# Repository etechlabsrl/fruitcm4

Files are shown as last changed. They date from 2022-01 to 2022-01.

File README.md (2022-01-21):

# Salmonberry Pi, Fruit \ 'früt \

<a href="https://www.raspberrypi.org">Raspberry Pi Logo</a>

> The Raspberry Pi is a series of credit card-sized single-board computers developed in the United Kingdom by the Raspberry Pi Foundation to promote the teaching of basic computer science in schools and developing countries. Official Link: [Raspberry Pi Foundation Homepage](https://raspberrypi.org), [Raspberry Pi Computer Homepage](https://www.raspberrypi.com)

<p>

Salmonberry Pi is a group of open source hardware projects which allow the construction of cluster hardware from small to arbitrary size using Raspberry Pi platforms.  This includes the Raspberry Pi Compute Module 4 (CM4) Raspberry Pi Zero 2 W, Raspberry Pi 4 Model B, and Raspberry Pi RP2040 microcontrollers.

The goals of this project are to provide:
- infrastructure for clustering nodes
- self-sufficient nodes by default (no 'leader')
- remotely monitoring
- remote management
- standard form factors and connectors, although perhaps repurposed

The component projects are:
- [Face CM4](https://github.com/salmonberrypi/facecm4), 8TE 3U faceplate with jacks, microSD card slot and LEDs.
- [Fruit CM4](https://github.com/salmonberrypi/fruitcm4), carrier board for CM4, general purpose compute or storage or both.
- [Graft](https://github.com/salmonberrypi/graft), development board to bring up Fruit board, allows diversion to on-board connectors for rhizome served power and signals. Can be used with or without rhizome boards. (out of date)
- [Thorn](https://github.com/salmonberrypi/thorn), passive board to protect the male plug on the Fruit or Graft boards. (out of date)
- [Rhizome](https://github.com/salmonberrypi/rhizome), life support systems and connectivity
- [Stem 3U x 160mm](https://github.com/salmonberrypi/stem_3U_160mm_X4), 3U x 160mm passive slot extension for debugging

(images are from a previous revision and out of date, shown for reference)

PCB front:

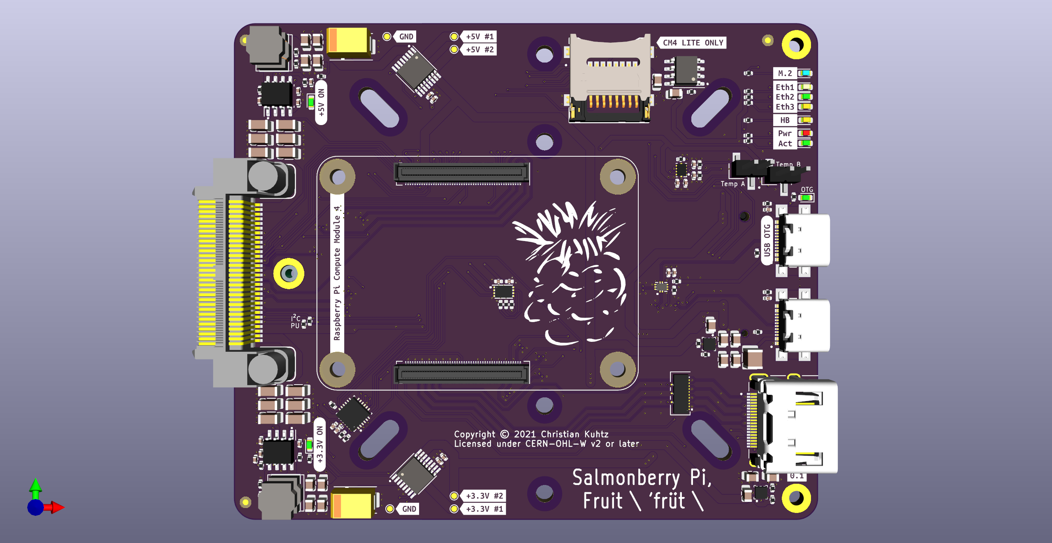
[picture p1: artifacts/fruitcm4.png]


PCB back:

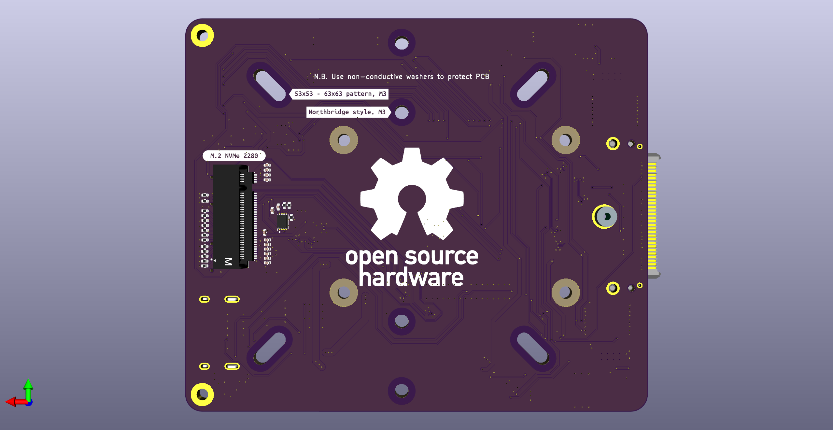
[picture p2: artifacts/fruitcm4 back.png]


Dimensions: 160 x 100mm (0.562 x 0.478 [bananas](http://bananaforscale.info/#!/convert/length/bananas/millimeters)) without connector and faceplate, 4 layer PCB (pwr/signal, gnd, gnd, pwr/signal).

Review [Interactive BOM](https://htmlpreview.github.io/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).

Review [Schematic](https://github.com/salmonberrypi/fruitcm4/blob/main/artifacts/fruitcm4%20schematic.pdf).

---

Designed in [KiCad 6](https://kicad.org) on [Ubuntu](https://ubuntu.org) 21.10 (impish).

---

Raspberry Pi is a trademark of Raspberry Pi Trading

---

Copyright (C) 2022 Christian Kuhtz

This source describes Open Hardware and is licensed under the CERN-OHLW v2
<P>
You may redistribute and modify this documentation and make products
using it under the terms of the CERN-OHL-W v2 (https:/cern.ch/cern-ohl).
<P>
This documentation is distributed WITHOUT ANY EXPRESS OR IMPLIED
WARRANTY, INCLUDING OF MERCHANTABILITY, SATISFACTORY QUALITY
AND FITNESS FOR A PARTICULAR PURPOSE. Please see the <a href="https://ohwr.org/cern_ohl_w_v2.txt">CERN-OHL-W v2</a> for applicable conditions.
<P>
Source location: https://github.com/salmonberrypi
<P>
As per CERN-OHL-W v2 section 4.1, should You produce hardware based on
these sources, You must maintain the Source Location visible on the
external case of the Salmonberry Pi or other product you make using
this documentation.

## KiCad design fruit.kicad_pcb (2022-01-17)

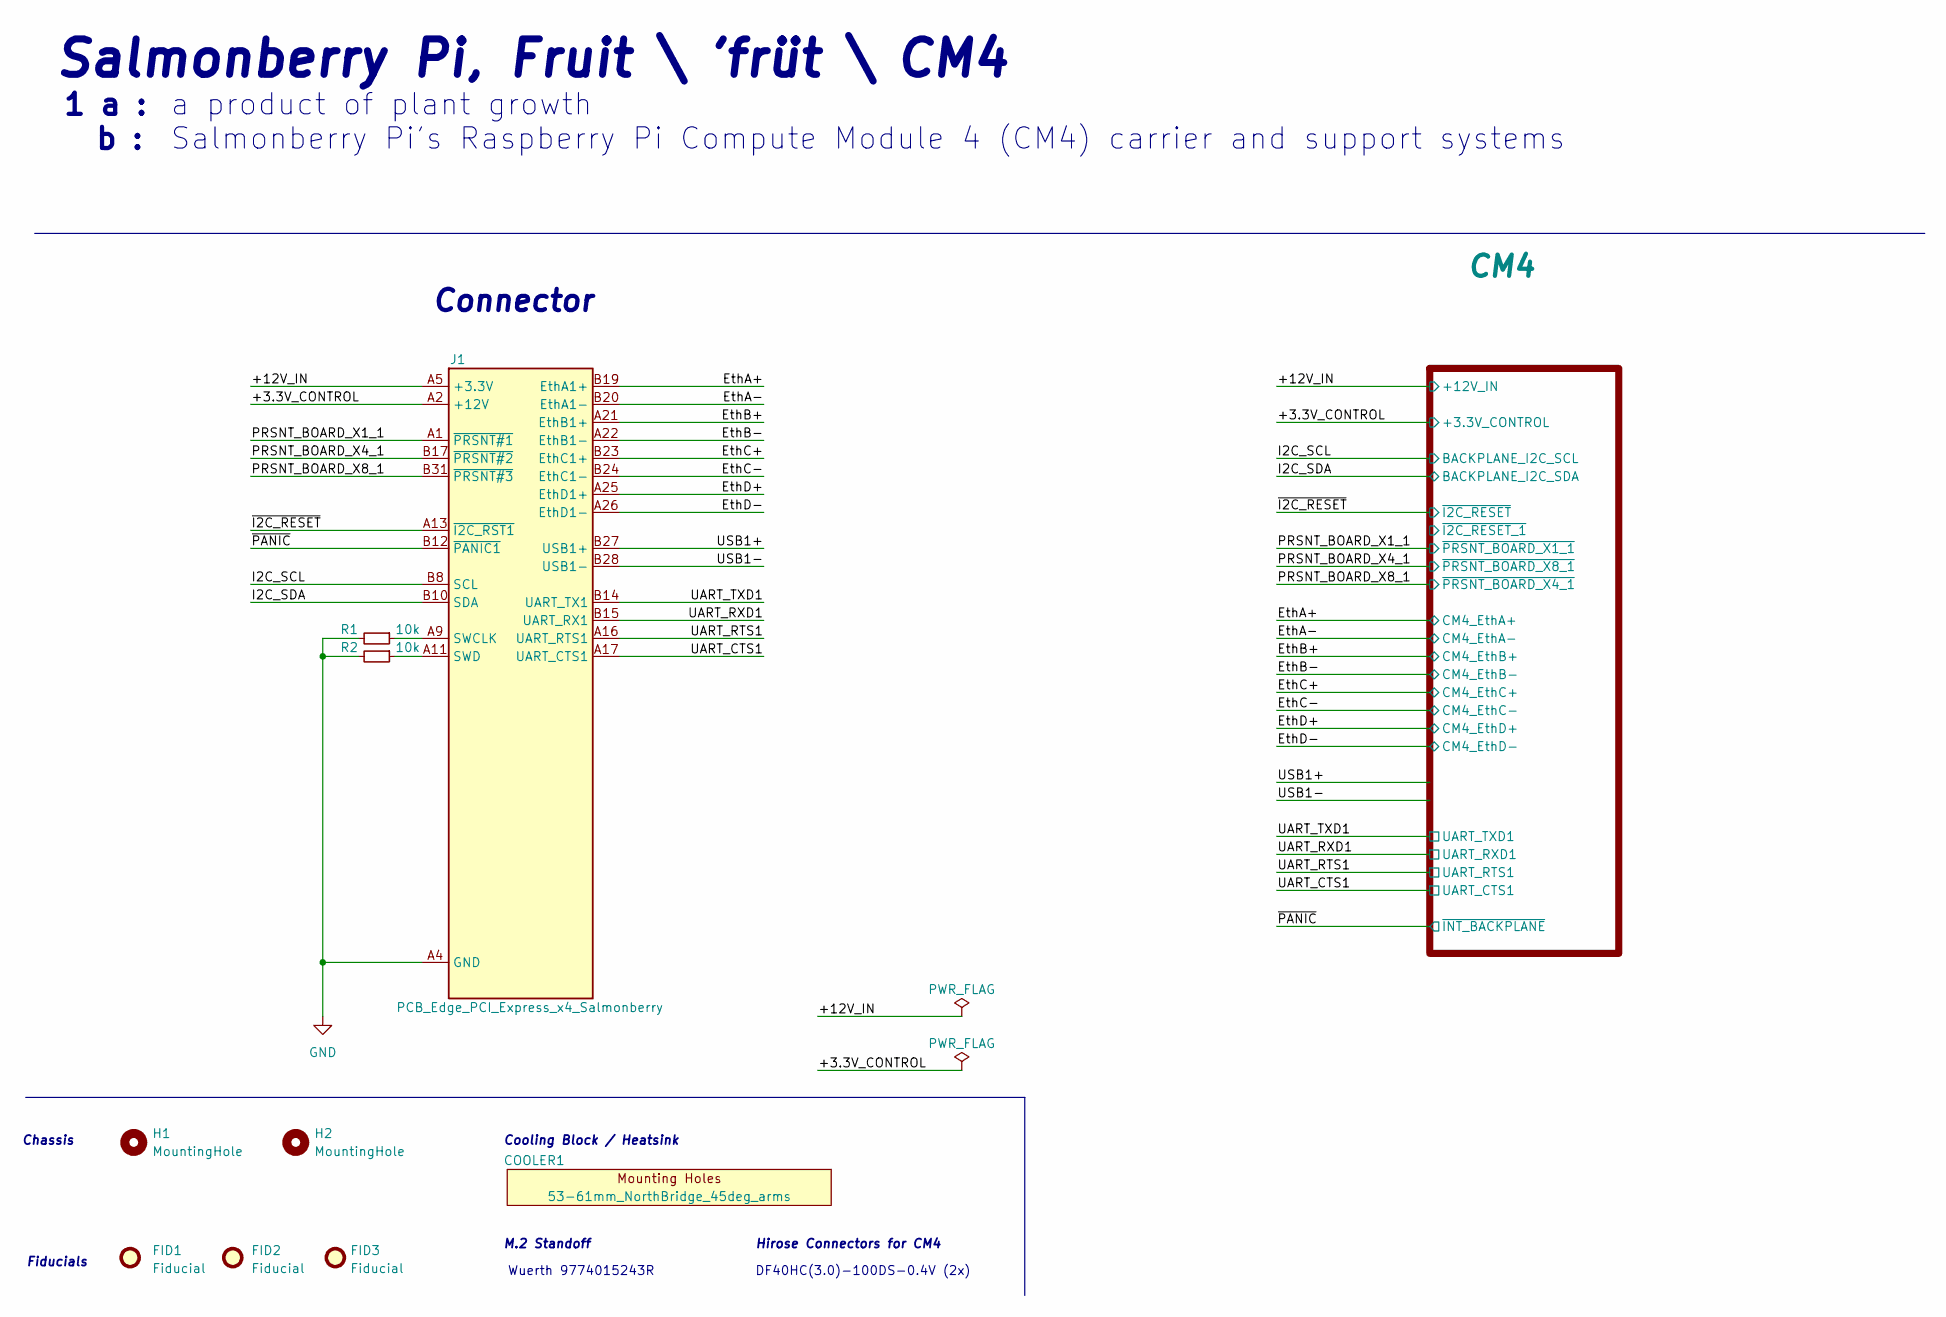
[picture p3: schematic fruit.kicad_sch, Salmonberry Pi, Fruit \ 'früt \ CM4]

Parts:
COOLER1: 53-61mm_NorthBridge_45deg_arms
FID1, FID2, FID3: Fiducial; Fiducial_1mm_Mask2mm
H1, H2: MountingHole; MountingHole_2.7mm_M2.5
J1: PCB_Edge_PCI_Express_x4_Salmonberry; BUS_PCIexpress_x4_Salmonberry_reduced_shoulders
R1, R2: 10k; R_0402_1005Metric

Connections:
+3.3V: J1.A5 (+3.3V), J1.A6 (+3.3V), J1.B5 (+3.3V), J1.B6 (+3.3V); also elsewhere on the board
+12V: J1.A2 (+12V), J1.A3 (+12V), J1.B1 (+12V), J1.B2 (+12V), J1.B3 (+12V); also elsewhere on the board
/EthA+: J1.B19 (EthA1+); also elsewhere on the board
/EthA-: J1.B20 (EthA1-); also elsewhere on the board
/EthB+: J1.A21 (EthB1+); also elsewhere on the board
/EthB-: J1.A22 (EthB1-); also elsewhere on the board
/EthC+: J1.B23 (EthC1+); also elsewhere on the board
/EthC-: J1.B24 (EthC1-); also elsewhere on the board
/EthD+: J1.A25 (EthD1+); also elsewhere on the board
/EthD-: J1.A26 (EthD1-); also elsewhere on the board
/I2C_SCL: J1.B8 (SCL); also elsewhere on the board
/I2C_SDA: J1.B10 (SDA); also elsewhere on the board
/PRSNT_BOARD_X1_1: J1.A1 (~PRSNT#1); also elsewhere on the board
/PRSNT_BOARD_X4_1: J1.B17 (~PRSNT#2); also elsewhere on the board
/PRSNT_BOARD_X8_1: J1.B31 (~PRSNT#3); also elsewhere on the board
/UART_CTS1: J1.A17 (UART_CTS1); also elsewhere on the board
/UART_RTS1: J1.A16 (UART_RTS1); also elsewhere on the board
/UART_RXD1: J1.B15 (UART_RX1); also elsewhere on the board
/UART_TXD1: J1.B14 (UART_TX1); also elsewhere on the board
/USB1+: J1.B27 (USB1+)
/USB1-: J1.B28 (USB1-)
/~I2C_RESET: J1.A13 (~I2C_RST1); also elsewhere on the board
/~PANIC: J1.B12 (~PANIC1); also elsewhere on the board
GND: J1.A4 (GND), J1.A7 (GND), J1.A8 (GND), J1.A10 (GND), J1.A12 (GND), J1.A14 (GND), J1.A15 (GND), J1.A18 (GND), J1.A19 (GND), J1.A20 (GND), J1.A23 (GND), J1.A24 (GND), J1.A27 (GND), J1.A28 (GND), J1.A29 (GND), J1.A30 (GND), J1.A31 (GND), J1.A32 (GND), J1.B4 (GND), J1.B7 (GND), J1.B9 (GND), J1.B11 (GND), J1.B13 (GND), J1.B16 (GND), J1.B18 (GND), J1.B21 (GND), J1.B22 (GND), J1.B25 (GND), J1.B26 (GND), J1.B29 (GND), J1.B30 (GND), J1.B32 (GND), R1.2, R2.2; also elsewhere on the board
unnamed: J1.A9 (SWCLK), R1.1
unnamed: J1.A11 (SWD), R2.1

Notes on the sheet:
Cooling Block / Heatsink
M.2 Standoff
Salmonberry Pi, Fruit \ 'früt \ CM4
Fiducials
1 a : b :
a product of plant growth Salmonberry Pi's Raspberry Pi Compute Module 4 (CM4) carrier and support systems
Hirose Connectors for CM4
DF40HC(3.0)-100DS-0.4V (2x)
Chassis
Wuerth 9774015243R
Connector

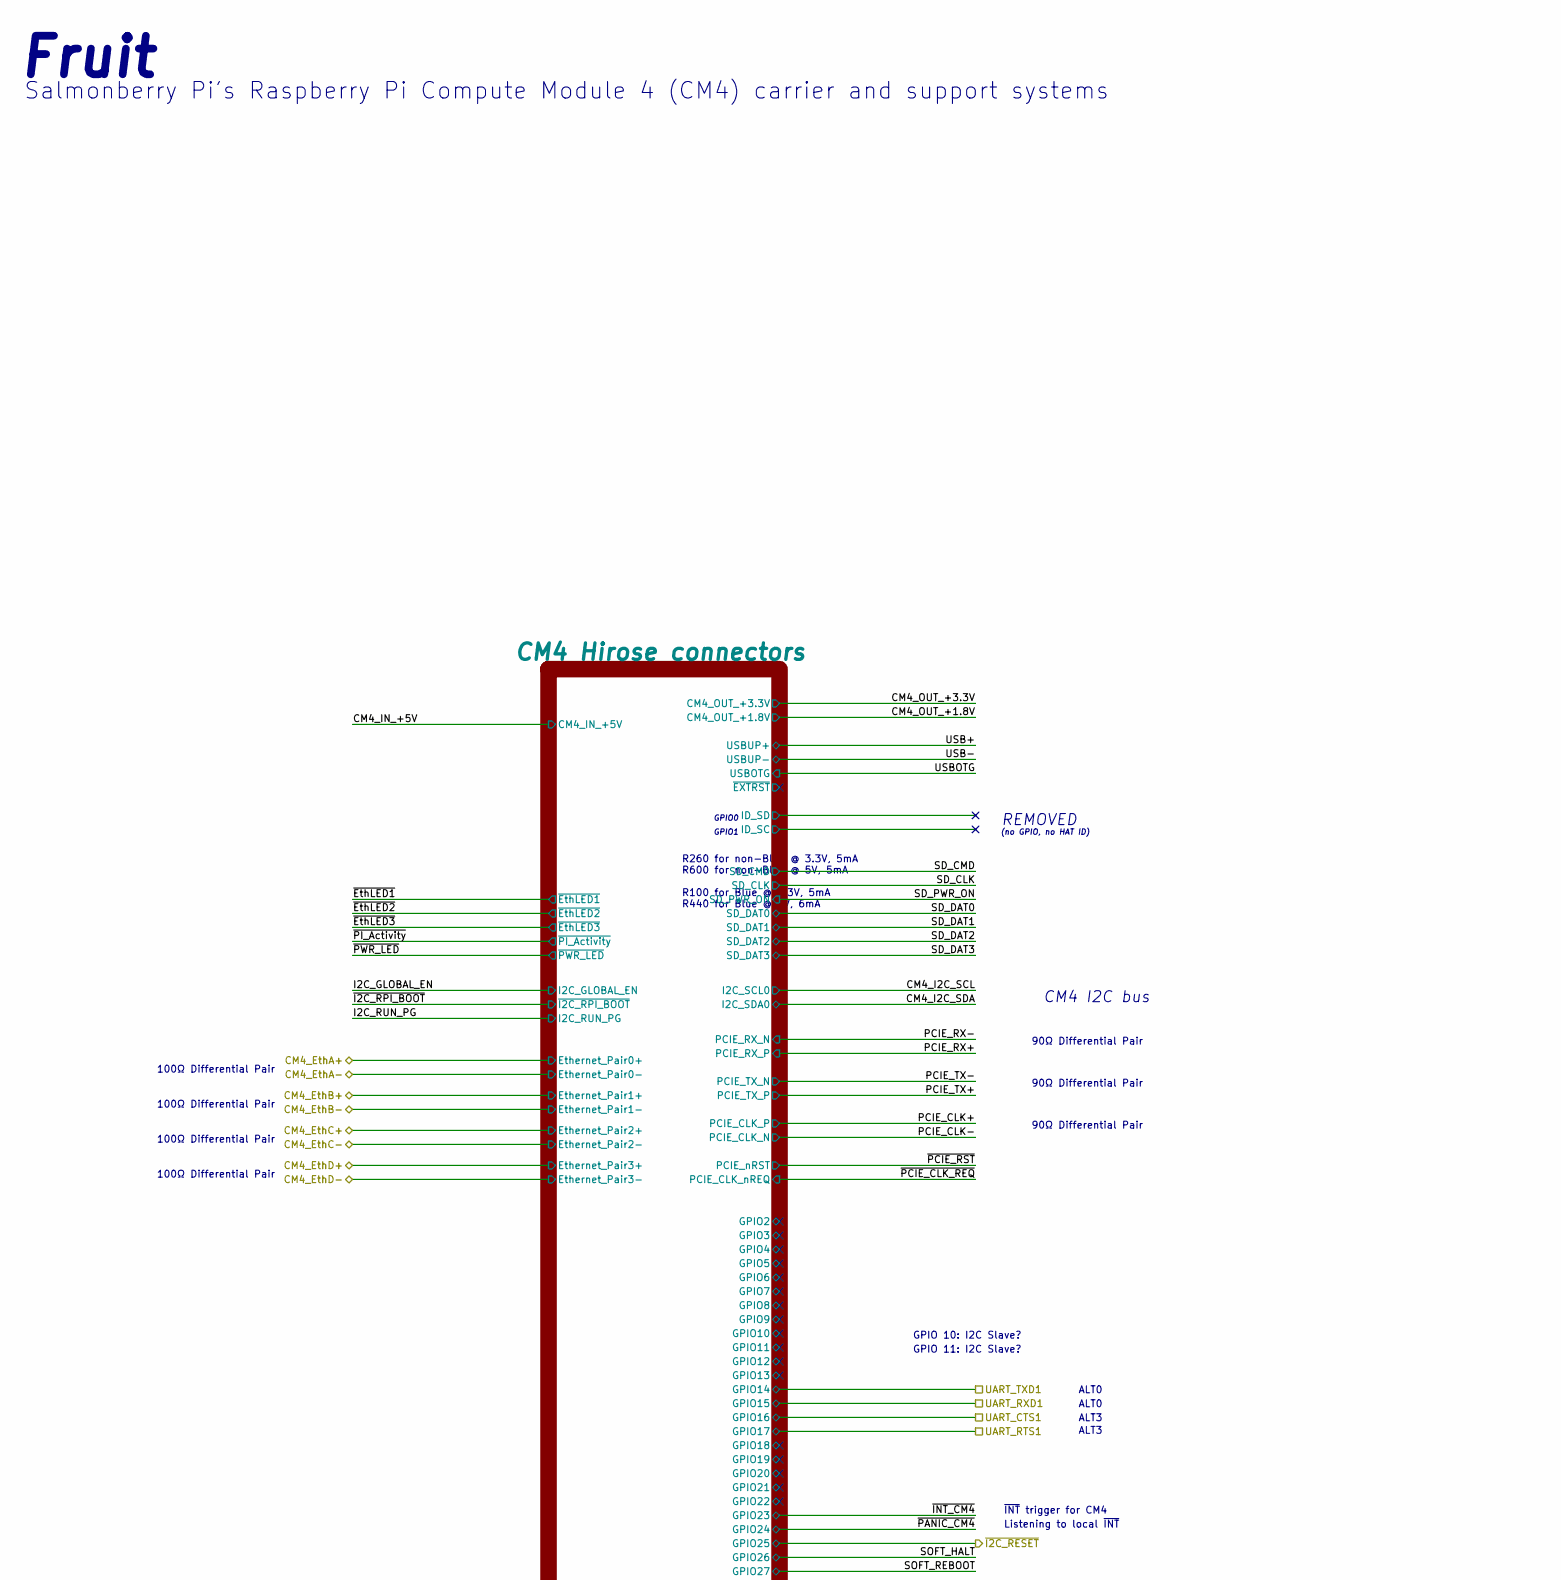
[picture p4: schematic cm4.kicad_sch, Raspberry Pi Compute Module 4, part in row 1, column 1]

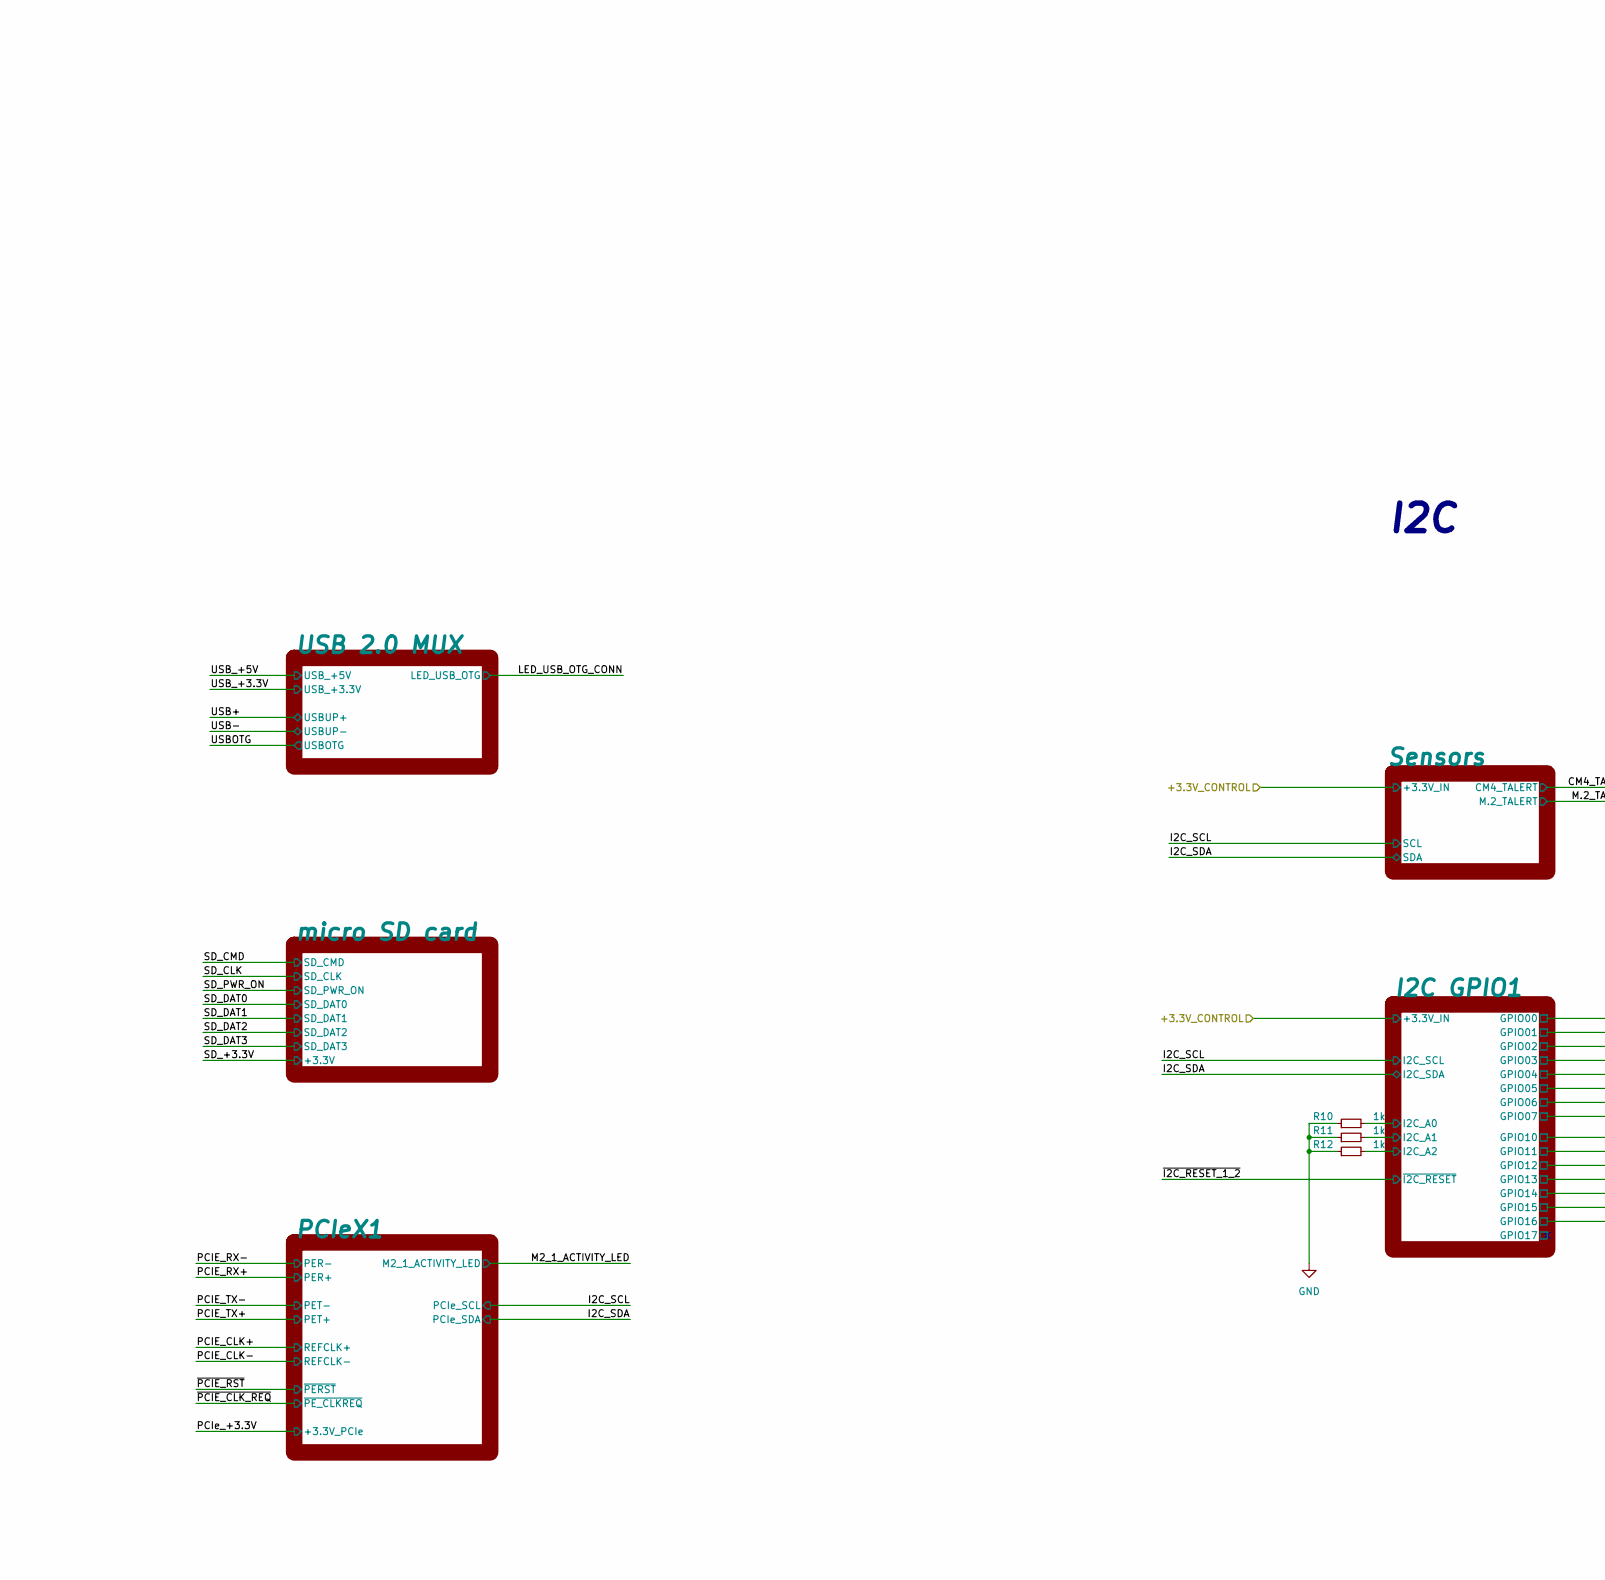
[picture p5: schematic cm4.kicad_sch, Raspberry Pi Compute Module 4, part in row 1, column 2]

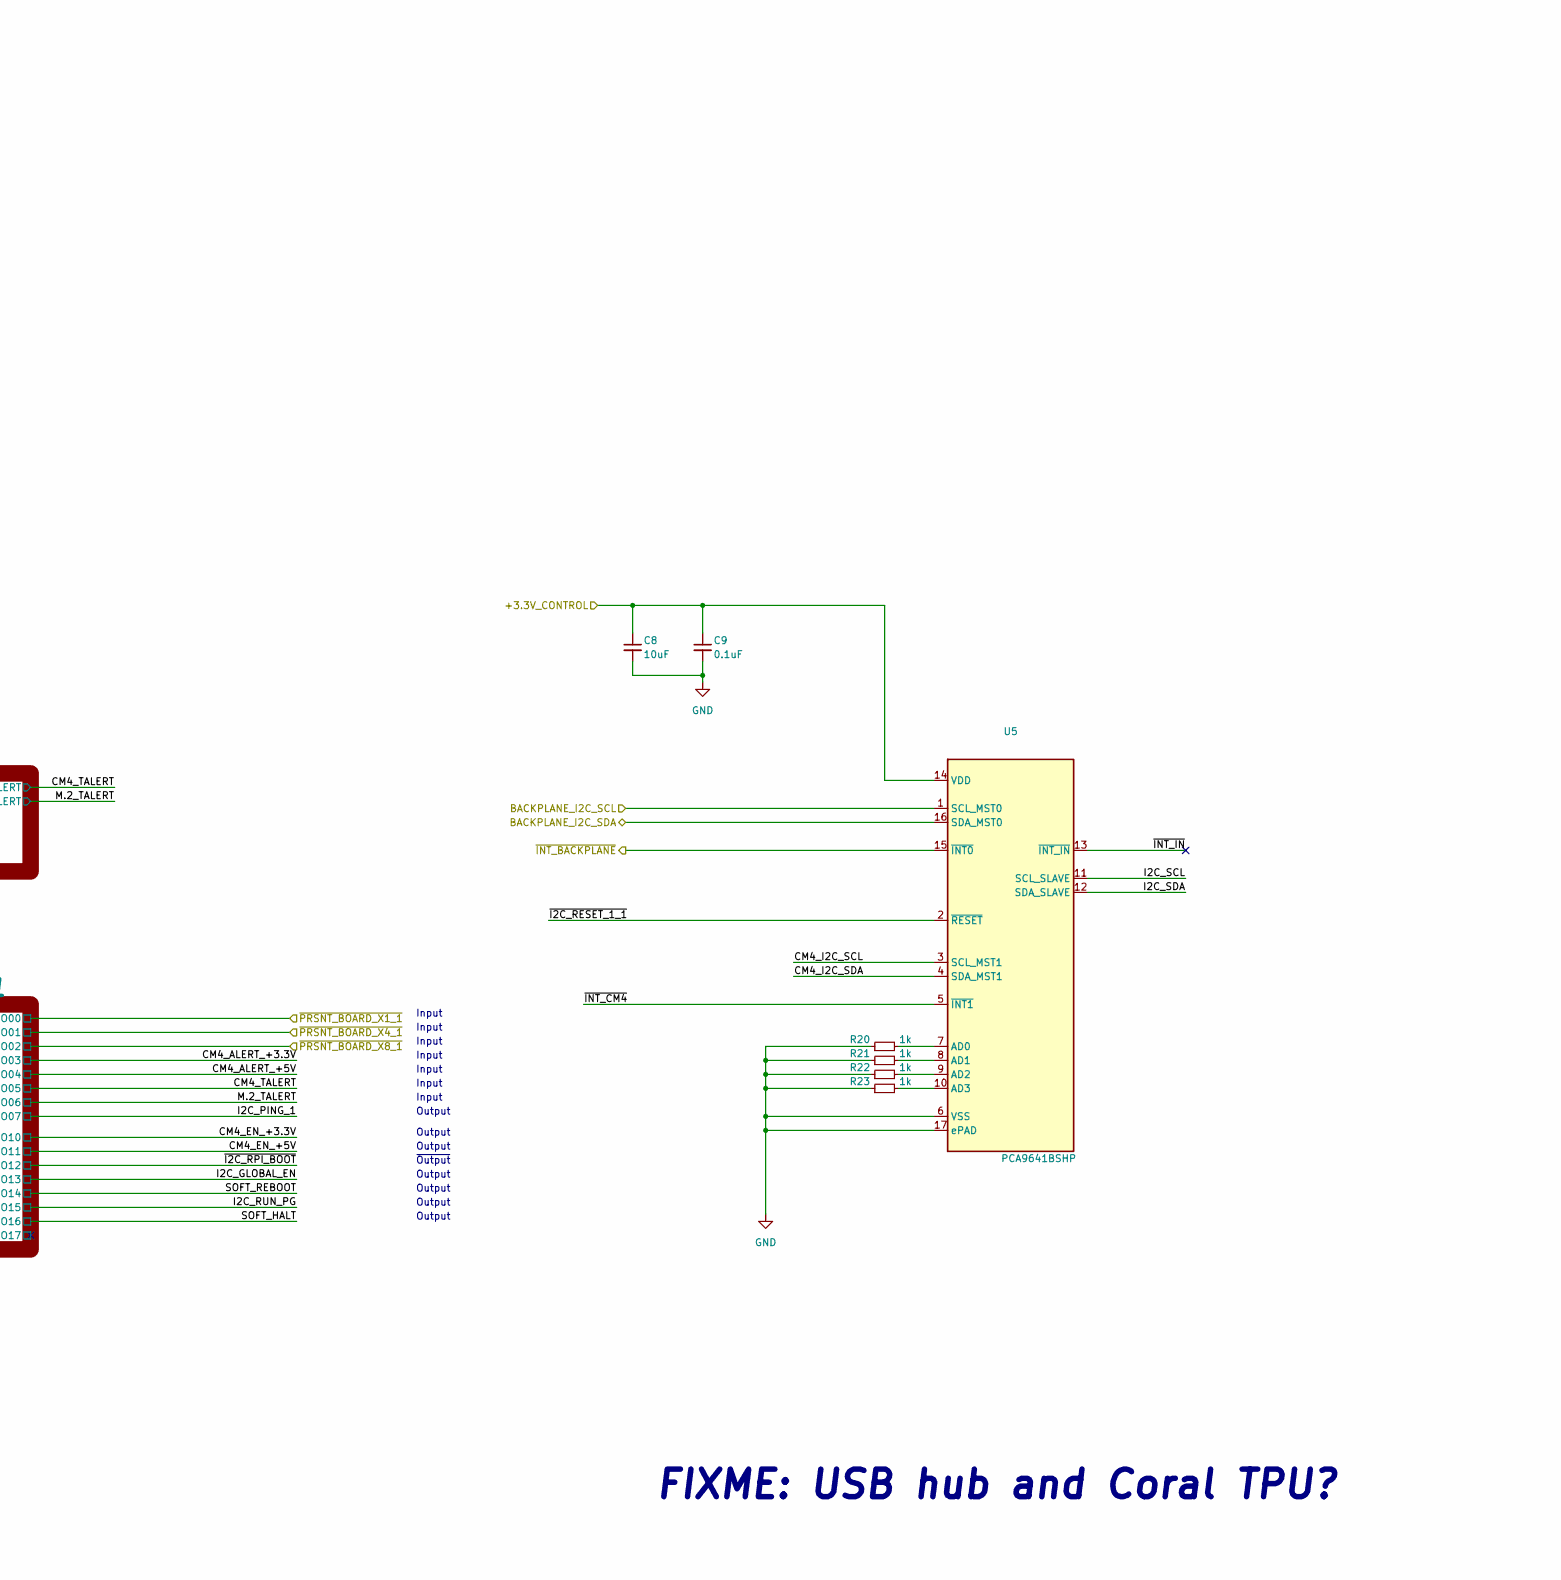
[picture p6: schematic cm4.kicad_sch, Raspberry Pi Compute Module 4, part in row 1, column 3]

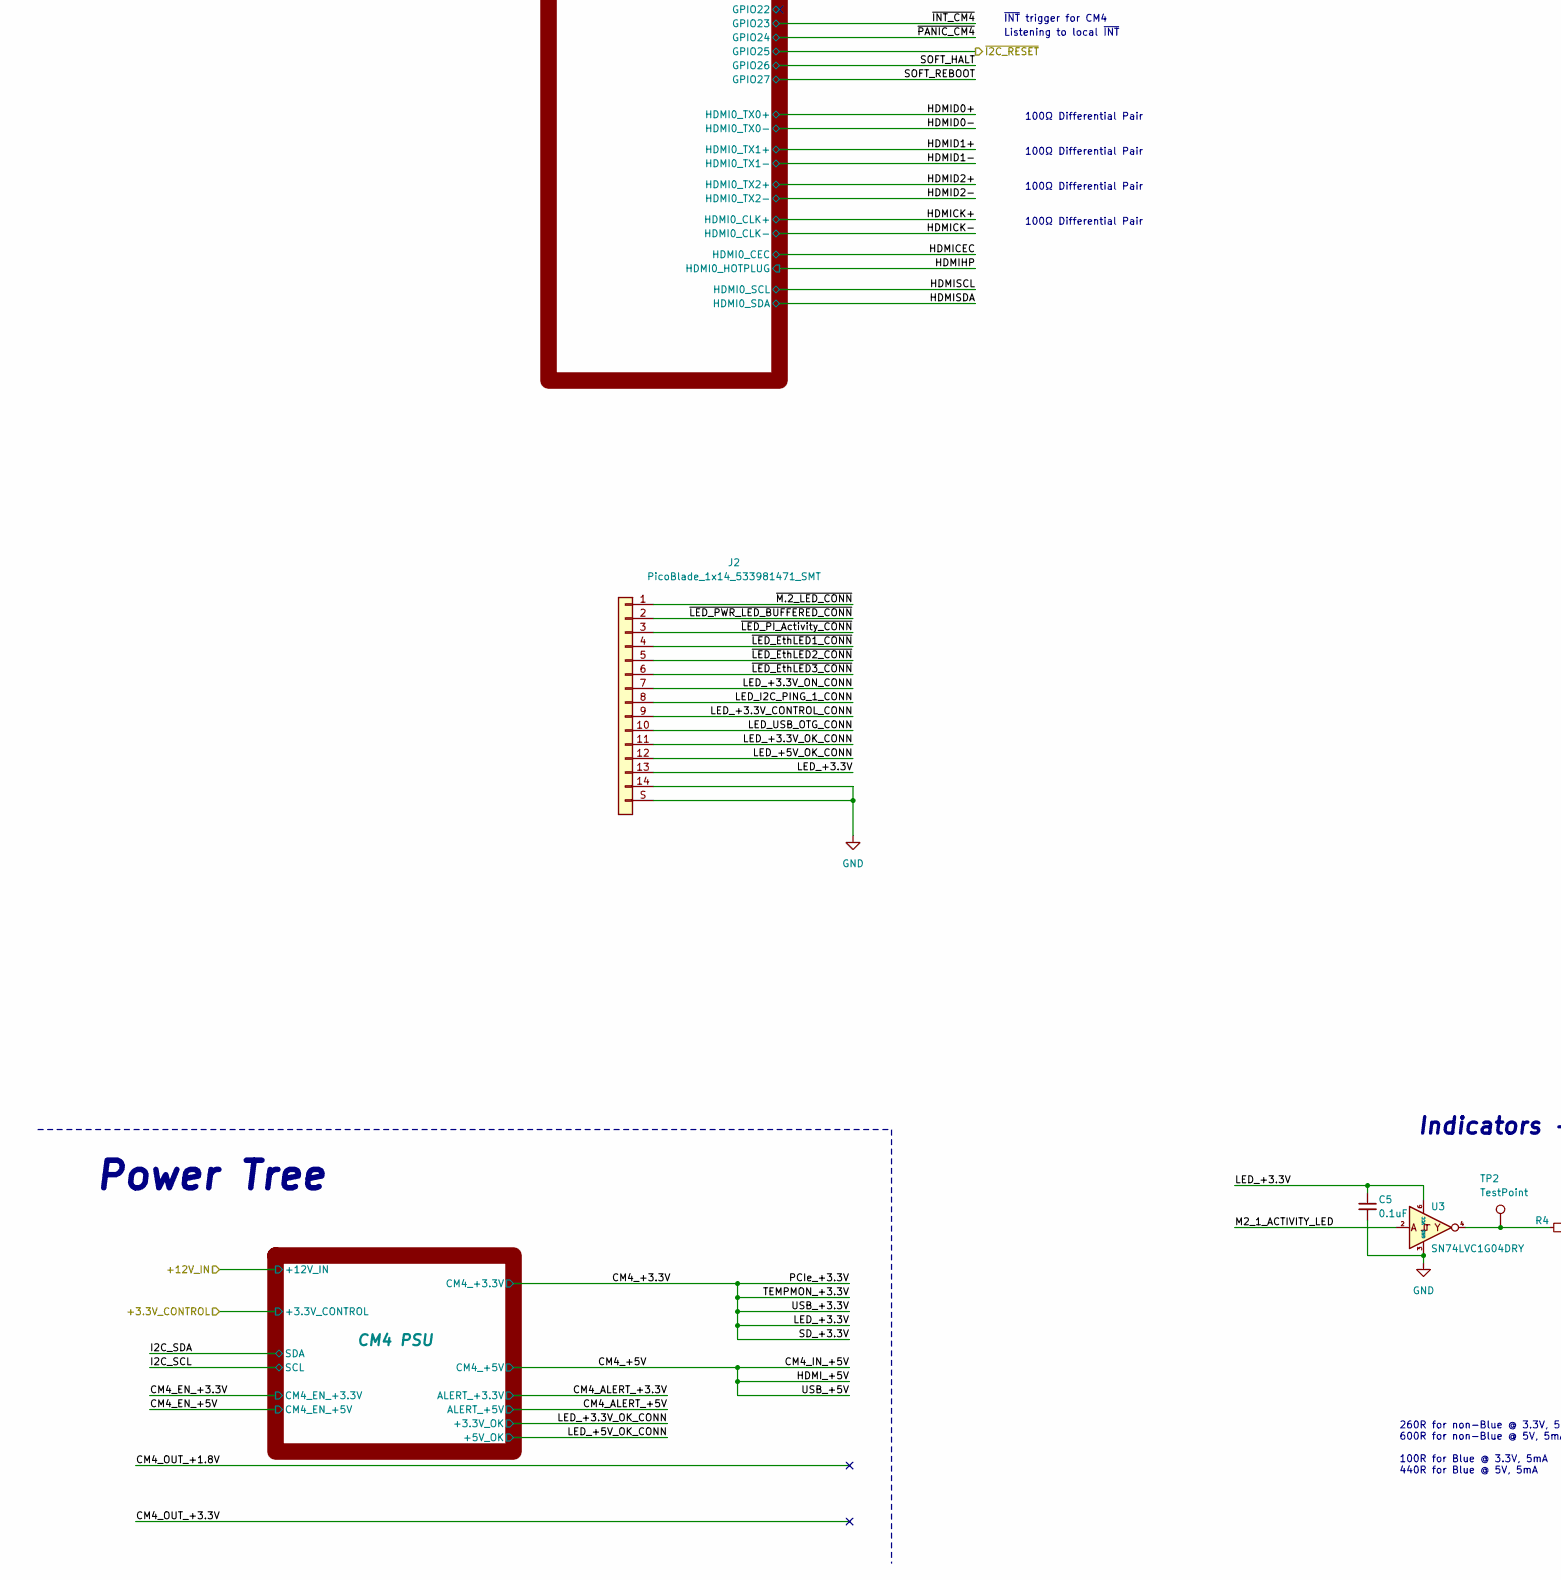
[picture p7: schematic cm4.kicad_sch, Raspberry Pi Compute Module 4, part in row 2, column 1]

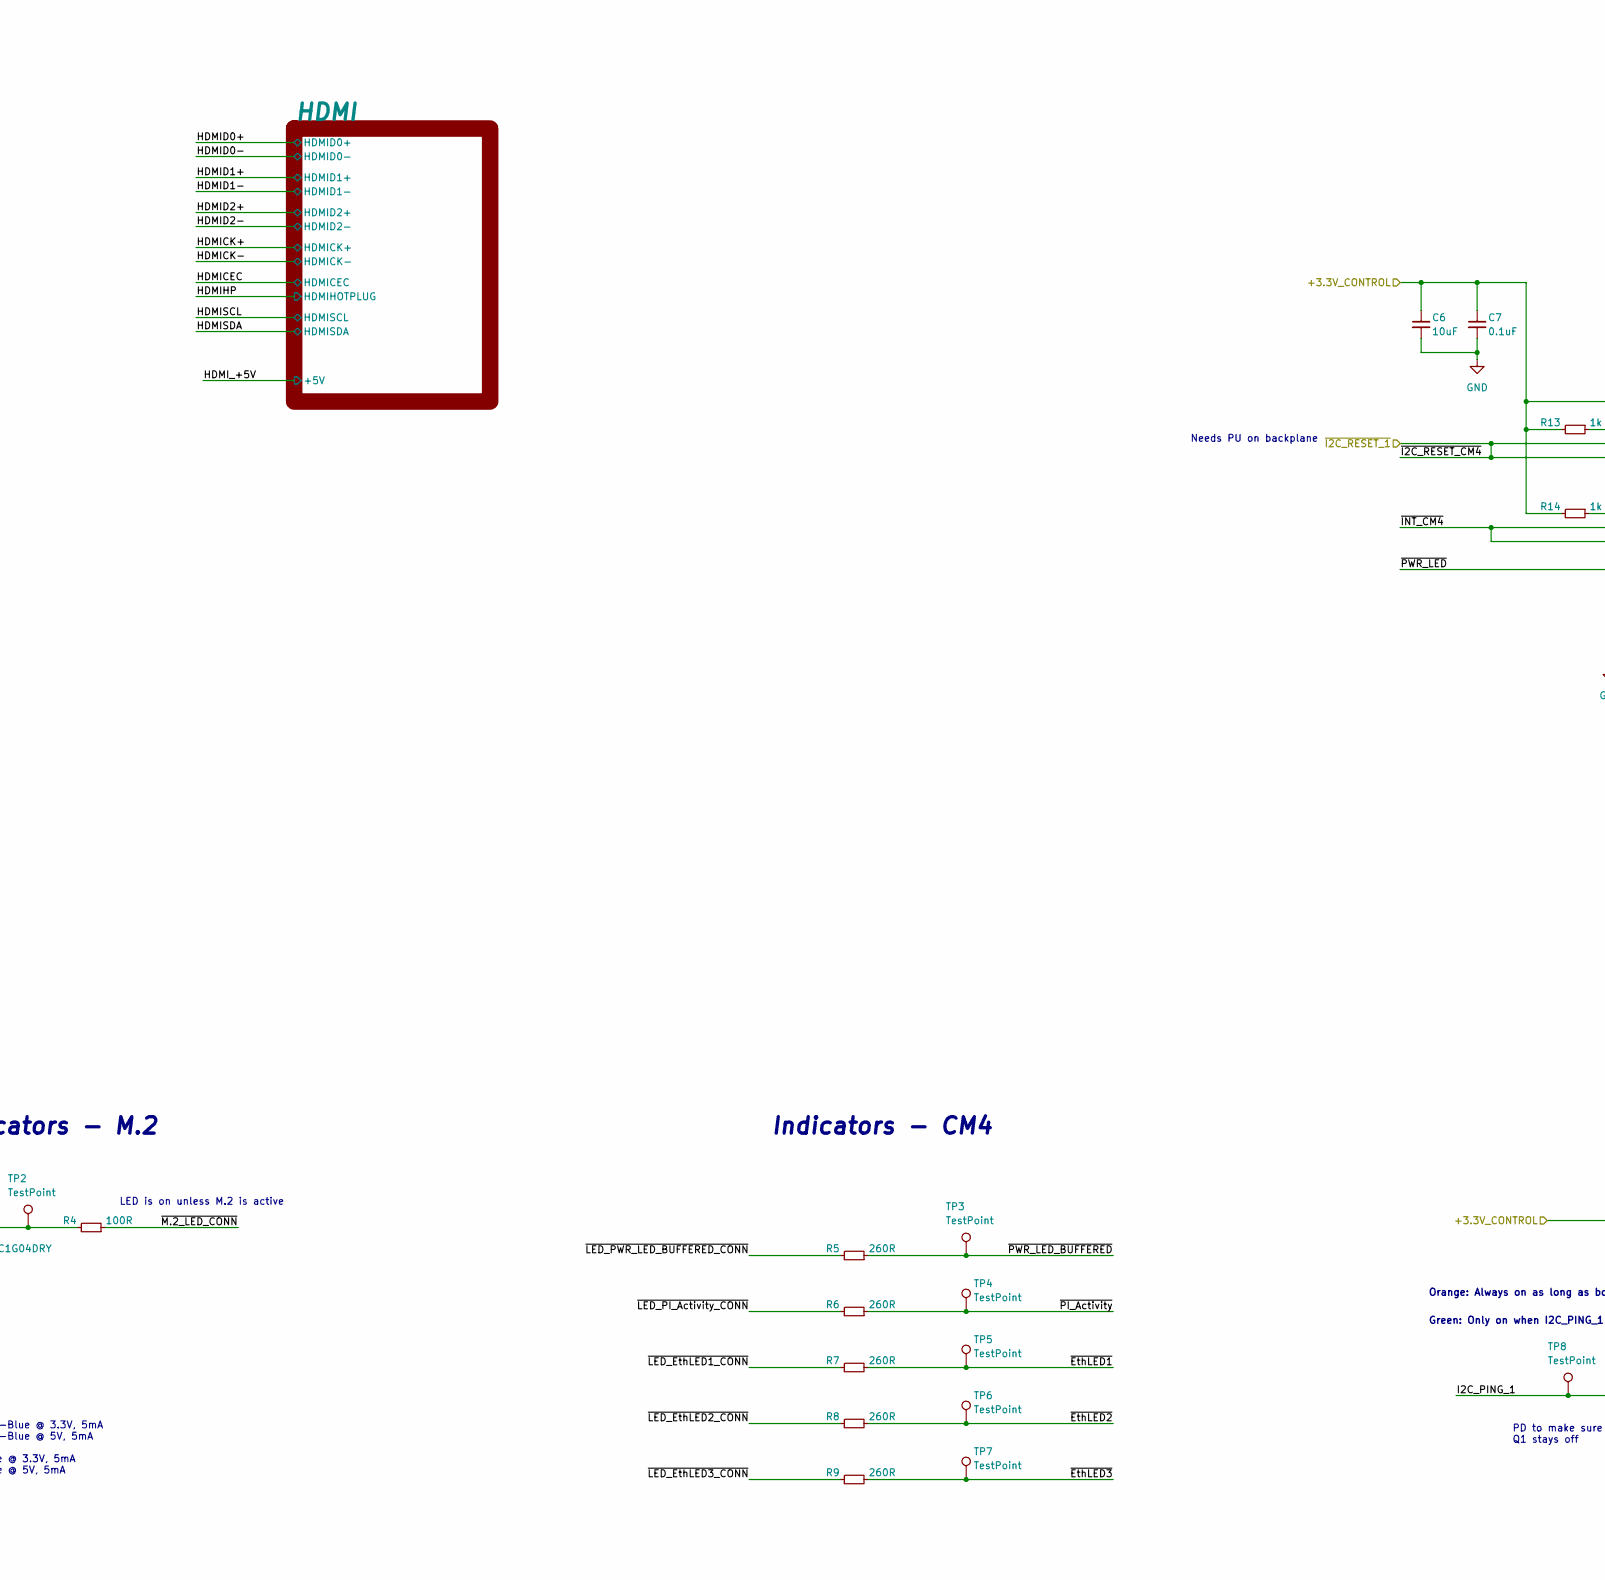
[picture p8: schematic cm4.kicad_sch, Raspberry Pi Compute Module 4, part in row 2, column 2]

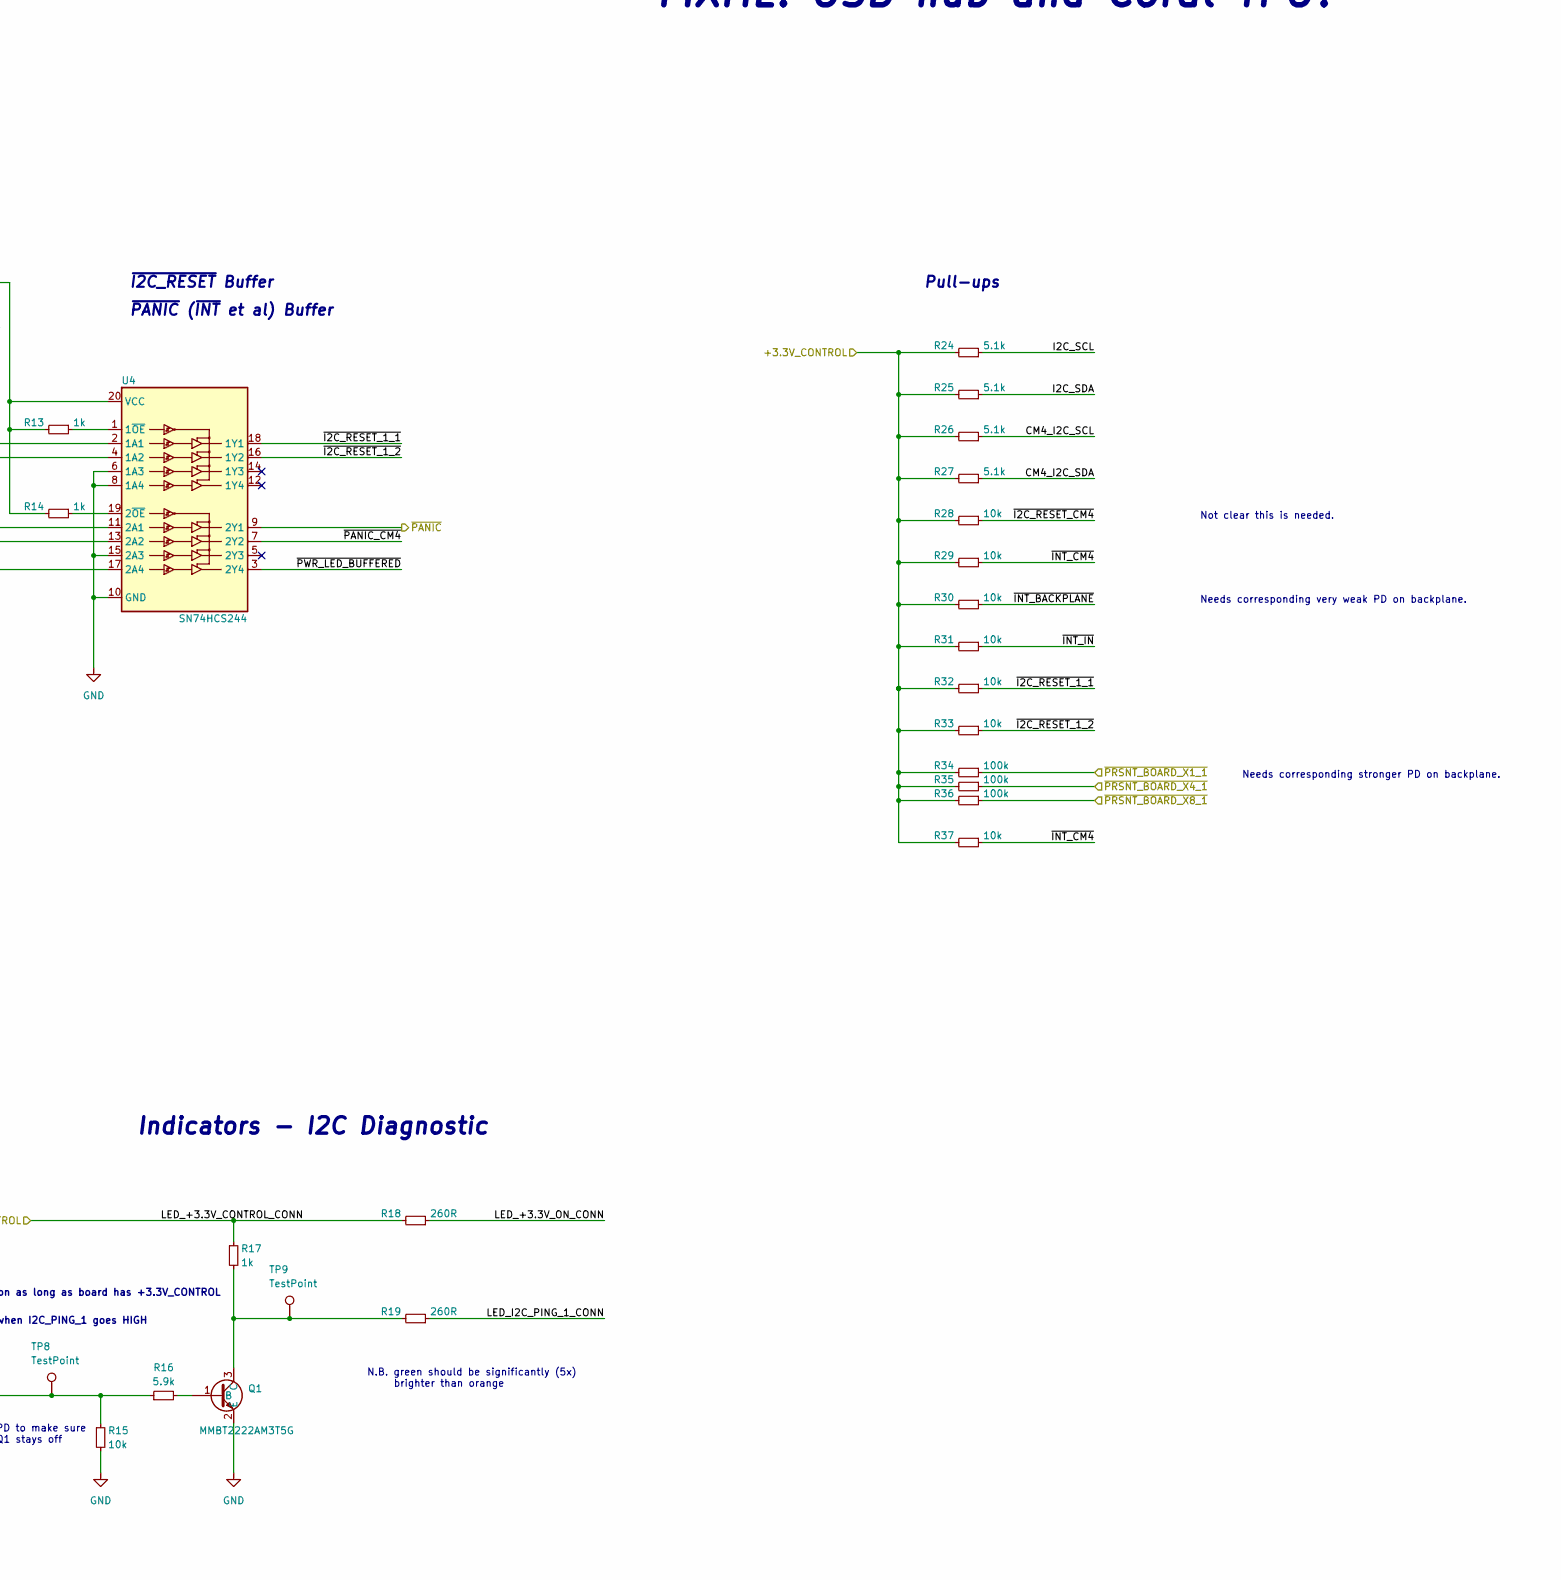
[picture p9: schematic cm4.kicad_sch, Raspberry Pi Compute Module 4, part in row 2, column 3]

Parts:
C5, C7, C9: 0.1uF; C_0402_1005Metric
C6, C8: 10uF; C_0402_1005Metric
J2: PicoBlade_1x14_533981471_SMT; MOLEX_533981471; MPN 533981471
Q1: MMBT2222AM3T5G; MPN MMBT2222AM3T5G
R4: 100R; R_0402_1005Metric
R5, R6, R7, R8, R9, R18, R19: 260R; R_0402_1005Metric
R10, R11, R12, R13, R14, R17, R20, R21, R22, R23: 1k; R_0402_1005Metric
R15, R28, R29, R30, R31, R32, R33, R37: 10k; R_0402_1005Metric
R16: 5.9k; R_0402_1005Metric
R24, R25, R26, R27: 5.1k; R_0402_1005Metric
R34, R35, R36: 100k; R_0402_1005Metric
TP2, TP3, TP4, TP5, TP6, TP7, TP8, TP9: TestPoint; TestPoint_Pad_D1.0mm
U3: SN74LVC1G04DRY; PSON50P145X100X60-6N-DRY0006A; MPN SN74LVC1G04DRY
U4: SN74HCS244; RKS0020A; MPN SN74HCS244RKSR
U5: PCA9641BSHP; SOT758-1_HVQFN-16_3x3mm_P0.5mm_EP1.75x1.75mm_NXP; MPN PCA9641BSHP

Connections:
+12V: C6.1, C7.1, C8.1, C9.1, J2.9, R13.2, R14.2, R17.1, R18.2, R24.2, R25.2, R26.2, R27.2, R28.2, R29.2, R30.2, R31.2, R32.2, R33.2, R34.2, R35.2, R36.2, R37.2, U4.20 (VCC), U5.14 (VDD); also elsewhere on the board
/CM4/CM4_+3.3V: C5.1, J2.13, U3.6 (VCC); also elsewhere on the board
/CM4/CM4_I2C_SCL: R26.1, U5.3 (SCL_MST1); also elsewhere on the board
/CM4/CM4_I2C_SDA: R27.1, U5.4 (SDA_MST1); also elsewhere on the board
/CM4/I2C GPIO1/I2C_A0: R10.2; also elsewhere on the board
/CM4/I2C GPIO1/I2C_A1: R11.2; also elsewhere on the board
/CM4/I2C GPIO1/I2C_A2: R12.2; also elsewhere on the board
/CM4/I2C_PING_1: R15.1, R16.1, TP8.1; also elsewhere on the board
/CM4/I2C_SCL: R24.1, U5.11 (SCL_SLAVE); also elsewhere on the board
/CM4/I2C_SDA: R25.1, U5.12 (SDA_SLAVE); also elsewhere on the board
/CM4/LED_+3.3V_OK_CONN: J2.11; also elsewhere on the board
/CM4/LED_+3.3V_ON_CONN: J2.7, R18.1
/CM4/LED_+5V_OK_CONN: J2.12; also elsewhere on the board
/CM4/LED_I2C_PING_1_CONN: J2.8, R19.1
/CM4/LED_USB_OTG_CONN: J2.10; also elsewhere on the board
/CM4/M2_1_ACTIVITY_LED: U3.2; also elsewhere on the board
/CM4/~EthLED1: R7.2, TP5.1; also elsewhere on the board
/CM4/~EthLED2: R8.2, TP6.1; also elsewhere on the board
/CM4/~EthLED3: R9.2, TP7.1; also elsewhere on the board
/CM4/~I2C_RESET_1_1: R32.1, U4.18 (1Y1), U5.2 (~RESET)
/CM4/~I2C_RESET_1_2: R33.1, U4.16 (1Y2); also elsewhere on the board
/CM4/~I2C_RESET_CM4: R28.1, U4.2 (1A1), U4.4 (1A2)
/CM4/~INT_CM4: R29.1, R37.1, U4.11 (2A1), U4.13 (2A2), U5.5 (~INT1); also elsewhere on the board
/CM4/~INT_IN: R31.1, U5.13 (~INT_IN)
/CM4/~LED_EthLED1_CONN: J2.4, R7.1
/CM4/~LED_EthLED2_CONN: J2.5, R8.1
/CM4/~LED_EthLED3_CONN: J2.6, R9.1
/CM4/~LED_PI_Activity_CONN: J2.3, R6.2
/CM4/~LED_PWR_LED_BUFFERED_CONN: J2.2, R5.2
/CM4/~M.2_LED_CONN: J2.1, R4.1
/CM4/~PANIC_CM4: U4.7 (2Y2); also elsewhere on the board
/CM4/~PANIC: U4.9 (2Y1)
/CM4/~PI_Activity: R6.1, TP4.1; also elsewhere on the board
/CM4/~PWR_LED_BUFFERED: R5.1, TP3.1, U4.3 (2Y4)
/CM4/~PWR_LED: U4.17 (2A4); also elsewhere on the board
/I2C_SCL: U5.1 (SCL_MST0); also elsewhere on the board
/I2C_SDA: U5.16 (SDA_MST0); also elsewhere on the board
/PRSNT_BOARD_X1_1: R34.1; also elsewhere on the board
/PRSNT_BOARD_X4_1: R36.1; also elsewhere on the board
/PRSNT_BOARD_X8_1: R35.1; also elsewhere on the board
/~PANIC: R30.1, U5.15 (~INT0); also elsewhere on the board
GND: C5.2, C6.2, C7.2, C8.2, C9.2, J2.14, J2.S (SHIELD), Q1.2 (E), R10.1, R11.1, R12.1, R15.2, R20.1, R21.1, R22.1, R23.1, U3.3 (GND), U4.6 (1A3), U4.8 (1A4), U4.10 (GND), U4.15 (2A3), U4.21 (ePAD), U5.6 (VSS), U5.17 (ePAD); also elsewhere on the board
unnamed: Q1.1 (B), R16.2
unnamed: Q1.3 (C), R17.2, R19.2, TP9.1
unnamed: R4.2, TP2.1, U3.4
unnamed: R13.1, U4.1 (1~OE)
unnamed: R14.1, U4.19 (2~OE)
unnamed: R20.2, U5.7 (AD0)
unnamed: R21.2, U5.8 (AD1)
unnamed: R22.2, U5.9 (AD2)
unnamed: R23.2, U5.10 (AD3)

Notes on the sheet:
I2C
Output
100Ω Differential Pair
~{Output}
Orange: Always on as long as board has +3.3V_CONTROL
90Ω Differential Pair
(no GPIO, no HAT ID)
Indicators - I2C Diagnostic
ALT0
Input
Listening to local ~{INT}
GPIO 10: I2C Slave?
REMOVED
Needs PU on backplane
~{PANIC} (~{INT} et al) Buffer
ALT3
~{I2C_RESET} Buffer
PD to make sure Q1 stays off
Pull-ups
~{INT} trigger for CM4
N.B. green should be significantly (5x) brighter than orange
Indicators - CM4
Salmonberry Pi's Raspberry Pi Compute Module 4 (CM4) carrier and support systems
260R for non-Blue @ 3.3V, 5mA 600R for non-Blue @ 5V, 5mA 100R for Blue @ 3.3V, 5mA 440R for Blue @ 5V, 5mA
FIXME: USB hub and Coral TPU?
Needs corresponding very weak PD on backplane.
Green: Only on when I2C_PING_1 goes HIGH
R260 for non-Blue @ 3.3V, 5mA R600 for non-Blue @ 5V, 5mA R100 for Blue @ 3.3V, 5mA R440 for Blue @ 5V, 6mA
GPIO 11: I2C Slave?
Needs corresponding stronger PD on backplane.
Fruit
GPIO1
Indicators - M.2
Power Tree
Not clear this is needed.
GPIO0
CM4 I2C bus
LED is on unless M.2 is active

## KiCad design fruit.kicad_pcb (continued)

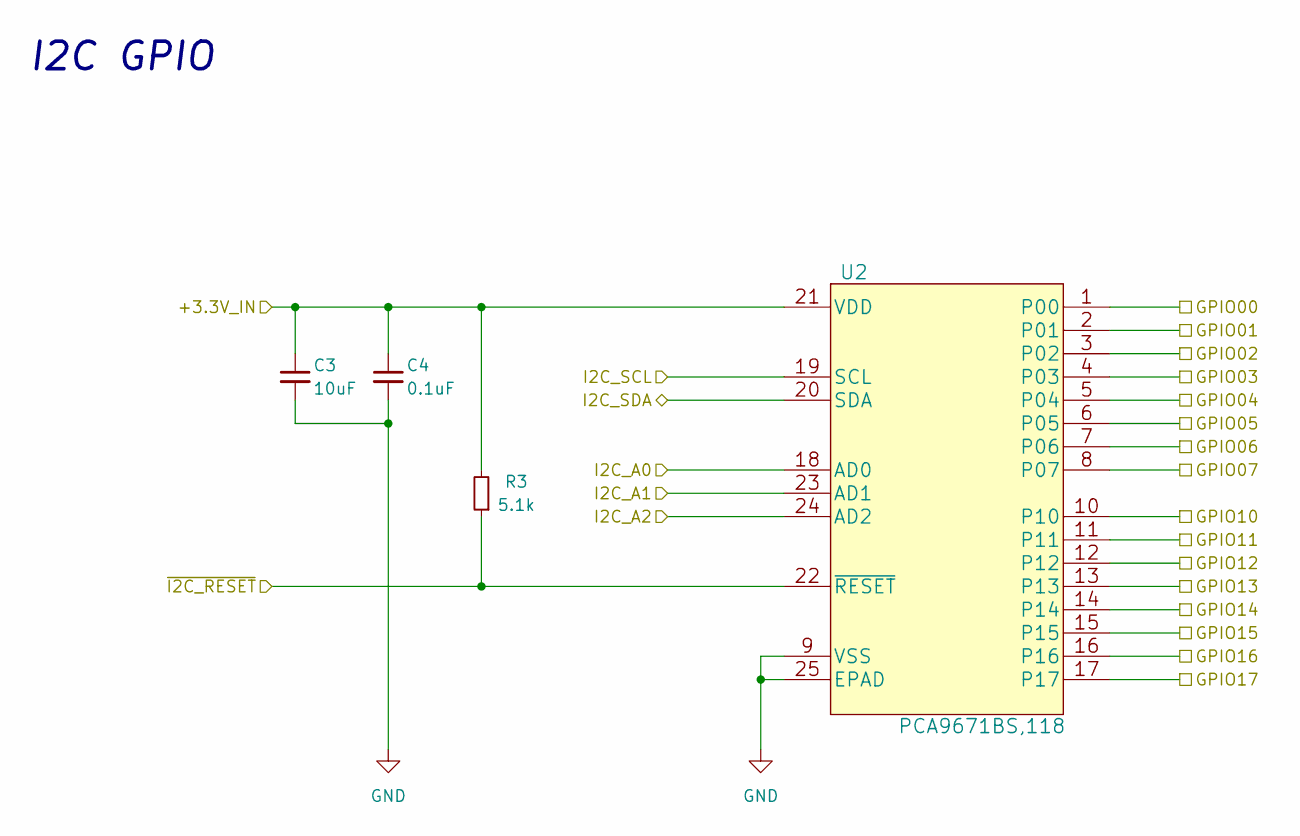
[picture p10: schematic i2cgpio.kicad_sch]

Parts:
C3: 10uF; C_0402_1005Metric
C4: 0.1uF; C_0402_1005Metric
R3: 5.1k; R_0402_1005Metric
U2: PCA9671BS,118; SOT616-1_HVQFN-24_4x4mm_P0.5mm_EP2.1x2.1mm_NXP; MPN PCA9671BS,118

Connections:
+12V: C3.1, C4.1, R3.2, U2.21 (VDD); also elsewhere on the board
/CM4/CM4_ALERT_+3.3V: U2.4 (P03); also elsewhere on the board
/CM4/CM4_ALERT_+5V: U2.5 (P04); also elsewhere on the board
/CM4/CM4_EN_+3.3V: U2.10; also elsewhere on the board
/CM4/CM4_EN_+5V: U2.11; also elsewhere on the board
/CM4/CM4_TALERT: U2.6 (P05); also elsewhere on the board
/CM4/I2C GPIO1/GPIO17: U2.17
/CM4/I2C GPIO1/I2C_A0: U2.18 (AD0); also elsewhere on the board
/CM4/I2C GPIO1/I2C_A1: U2.23 (AD1); also elsewhere on the board
/CM4/I2C GPIO1/I2C_A2: U2.24 (AD2); also elsewhere on the board
/CM4/I2C_GLOBAL_EN: U2.13; also elsewhere on the board
/CM4/I2C_PING_1: U2.8 (P07); also elsewhere on the board
/CM4/I2C_RUN_PG: U2.15; also elsewhere on the board
/CM4/I2C_SCL: U2.19 (SCL); also elsewhere on the board
/CM4/I2C_SDA: U2.20 (SDA); also elsewhere on the board
/CM4/M.2_TALERT: U2.7 (P06); also elsewhere on the board
/CM4/SOFT_HALT: U2.16; also elsewhere on the board
/CM4/SOFT_REBOOT: U2.14; also elsewhere on the board
/CM4/~I2C_RESET_1_2: R3.1, U2.22 (~RESET); also elsewhere on the board
/CM4/~I2C_RPI_BOOT: U2.12; also elsewhere on the board
/PRSNT_BOARD_X1_1: U2.1 (P00); also elsewhere on the board
/PRSNT_BOARD_X4_1: U2.3 (P02); also elsewhere on the board
/PRSNT_BOARD_X8_1: U2.2 (P01); also elsewhere on the board
GND: C3.2, C4.2, U2.9 (VSS), U2.25 (EPAD); also elsewhere on the board

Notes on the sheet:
I2C GPIO

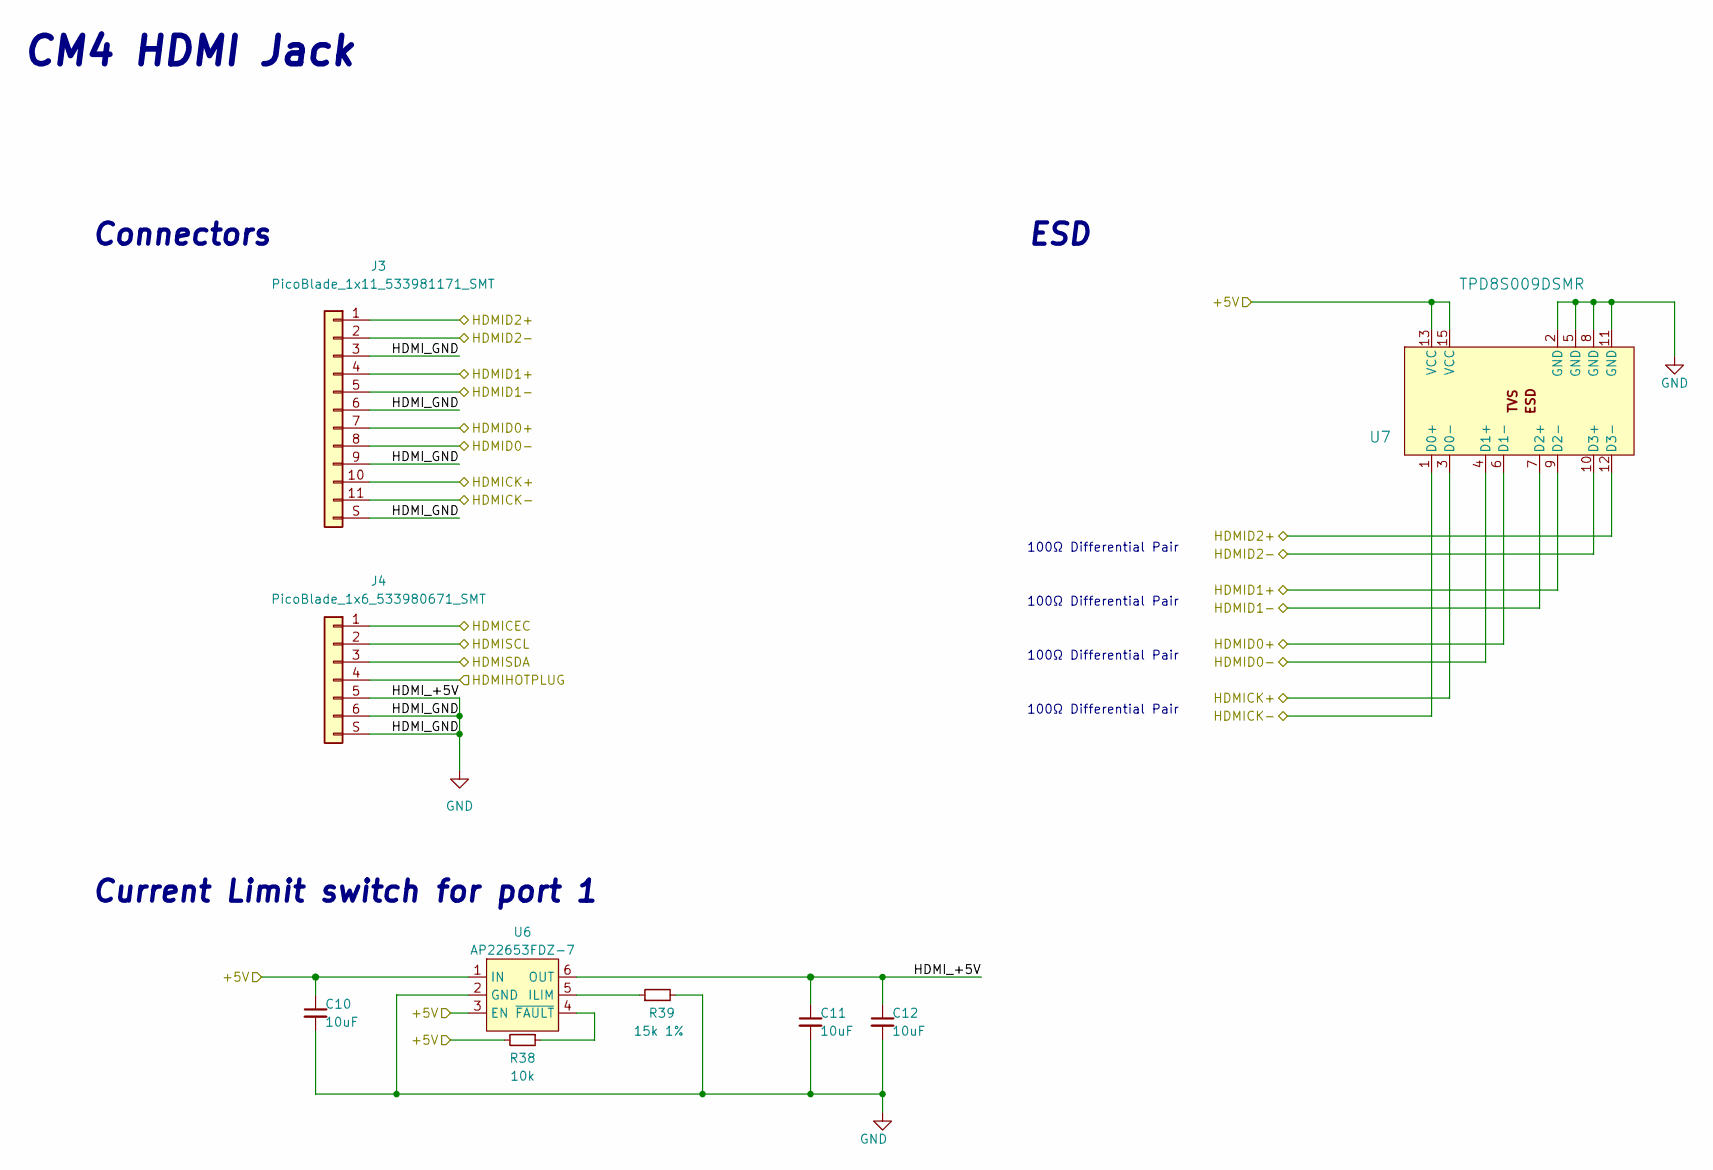
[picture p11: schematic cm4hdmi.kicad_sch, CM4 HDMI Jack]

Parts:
C10, C11, C12: 10uF; C_0805_2012Metric; Part Description 10uF 10% 10V Ceramic Capacitor X7R 0805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
J3: PicoBlade_1x11_533981171_SMT; MOLEX_533981171; MPN 533981171
J4: PicoBlade_1x6_533980671_SMT; MOLEX_533980671; MPN 533980771
R38: 10k; R_0402_1005Metric
R39: 15k 1%; R_0402_1005Metric; Part Description Resistor 15K M1005 1% 63mW
U6: AP22653FDZ-7; Diodes_W-DFN2020-6_A1; MPN AP22653FDZ-7
U7: TPD8S009DSMR; DSM15_X_reduced_paste_pin1; MPN TPD8S009DSMR

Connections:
/CM4/CM4_+5V: C10.1, R38.2, U6.1 (IN), U6.3 (EN), U7.13 (VCC), U7.15 (VCC); also elsewhere on the board
/CM4/HDMICEC: J4.1; also elsewhere on the board
/CM4/HDMICK+: J3.10, U7.3 (D0-); also elsewhere on the board
/CM4/HDMICK-: J3.11, U7.1 (D0+); also elsewhere on the board
/CM4/HDMID0+: J3.7, U7.6 (D1-); also elsewhere on the board
/CM4/HDMID0-: J3.8, U7.4 (D1+); also elsewhere on the board
/CM4/HDMID1+: J3.4, U7.9 (D2-); also elsewhere on the board
/CM4/HDMID1-: J3.5, U7.7 (D2+); also elsewhere on the board
/CM4/HDMID2+: J3.1, U7.12 (D3-); also elsewhere on the board
/CM4/HDMID2-: J3.2, U7.10 (D3+); also elsewhere on the board
/CM4/HDMIHP: J4.4; also elsewhere on the board
/CM4/HDMISCL: J4.2; also elsewhere on the board
/CM4/HDMISDA: J4.3; also elsewhere on the board
GND: C10.2, C11.1, C11.2, C12.1, C12.2, J3.3, J3.6, J3.9, J3.S (SHIELD), J4.5, J4.6, J4.S (SHIELD), R39.2, U6.2 (GND), U6.6 (OUT), U7.2 (GND), U7.5 (GND), U7.8 (GND), U7.11 (GND); also elsewhere on the board
unnamed: R38.1, U6.4 (~FAULT)
unnamed: R39.1, U6.5 (ILIM)

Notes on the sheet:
ESD
CM4 HDMI Jack
Connectors
100Ω Differential Pair
Current Limit switch for port 1

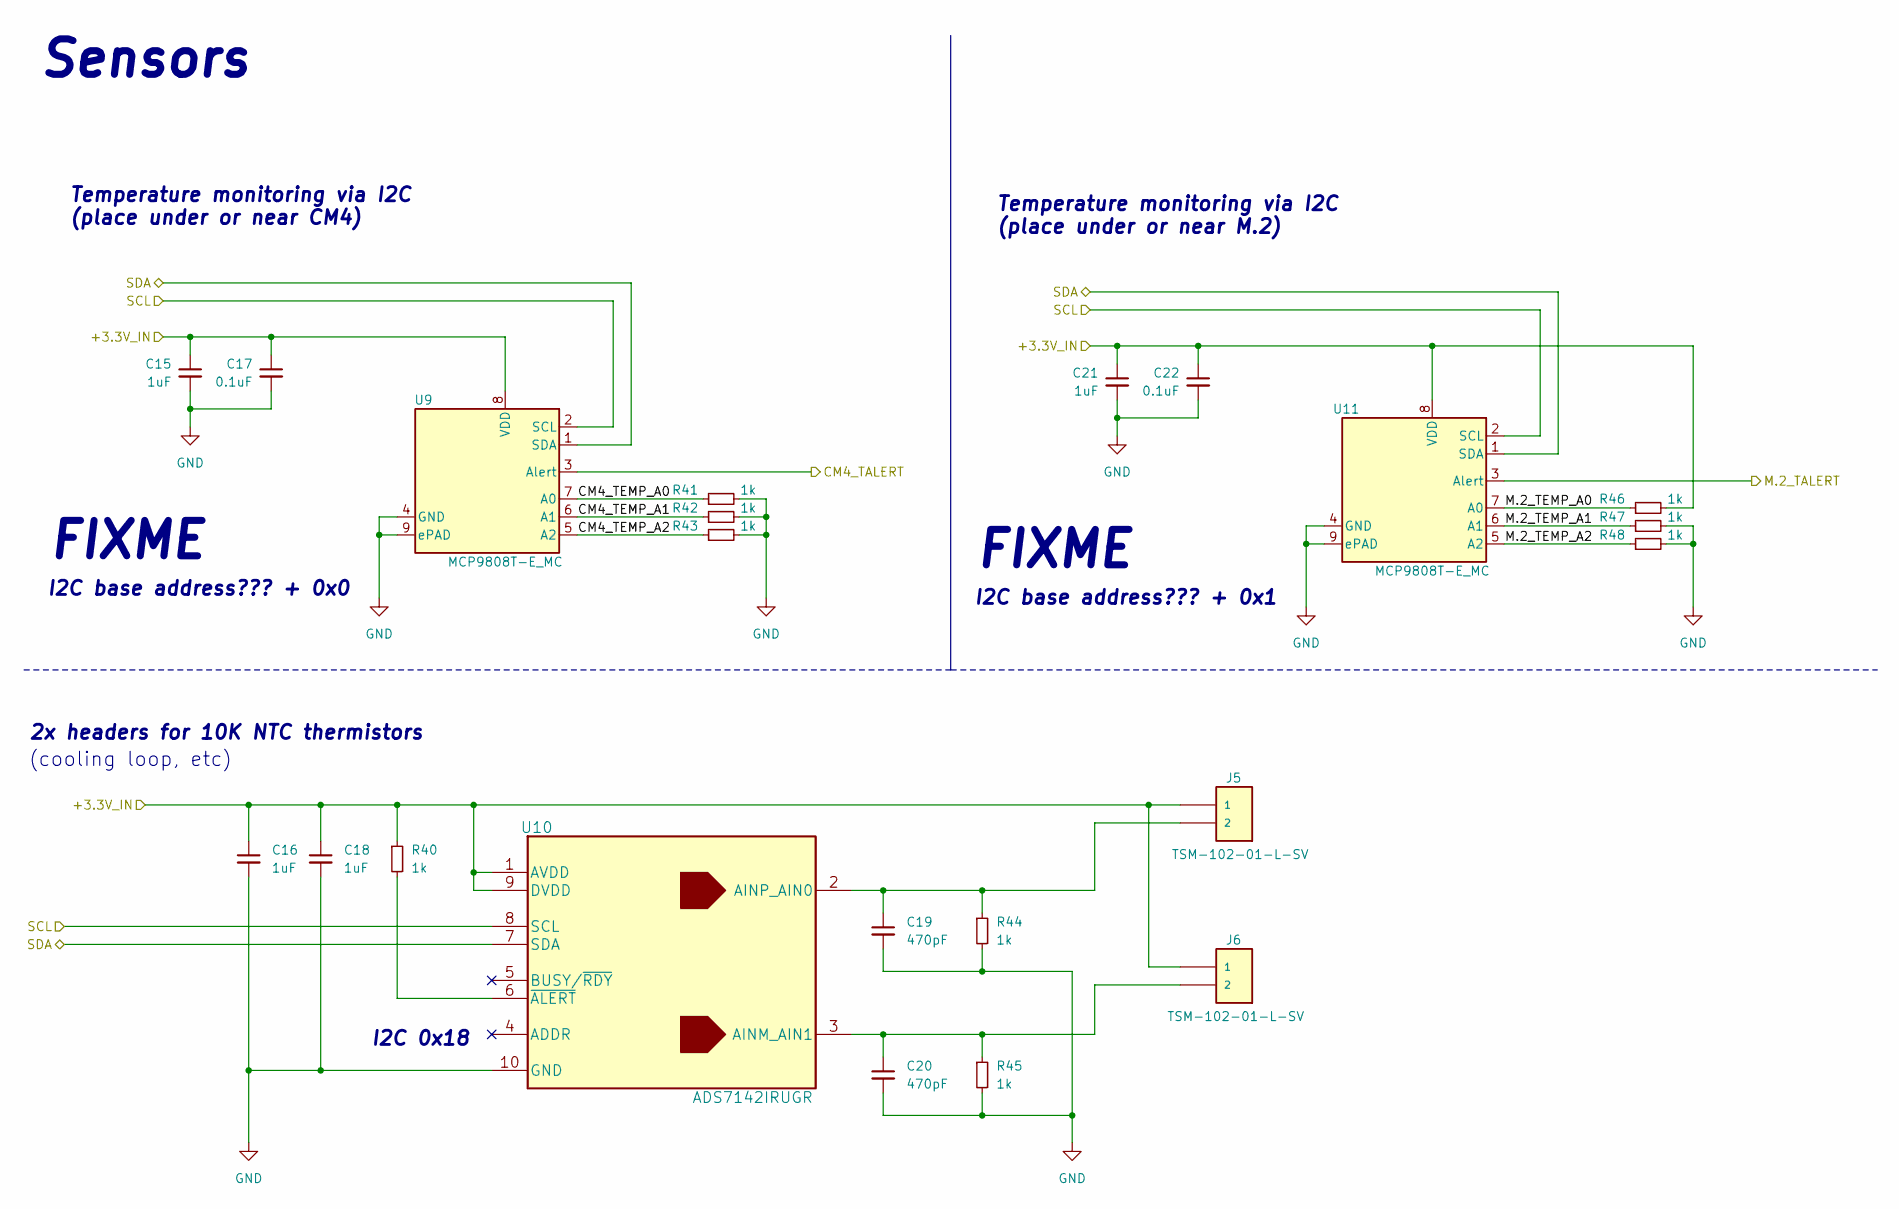
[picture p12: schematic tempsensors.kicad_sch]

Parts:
C15, C16, C18, C21: 1uF; C_0402_1005Metric
C17, C22: 0.1uF; C_0402_1005Metric
C19, C20: 470pF; C_0402_1005Metric
J5, J6: TSM-102-01-L-SV; SAMTEC_TSM-102-01-L-SV; MPN TSM-102-01-L-SV
R40, R41, R42, R43, R44, R45, R46, R47, R48: 1k; R_0402_1005Metric
U9, U11: MCP9808T-E_MC; MCP9808T-E&slash_MC
U10: ADS7142IRUGR; MPN ADS7142IRUGR

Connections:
+12V: C15.1, C16.1, C17.1, C18.1, C21.1, C22.1, J5.1, J6.1, R40.1, R46.2, U9.8 (VDD), U10.1 (AVDD), U10.9 (DVDD), U11.8 (VDD); also elsewhere on the board
/CM4/CM4_TALERT: U9.3 (Alert); also elsewhere on the board
/CM4/I2C_SCL: U9.2 (SCL), U10.8 (SCL), U11.2 (SCL); also elsewhere on the board
/CM4/I2C_SDA: U9.1 (SDA), U10.7 (SDA), U11.1 (SDA); also elsewhere on the board
/CM4/M.2_TALERT: U11.3 (Alert); also elsewhere on the board
/CM4/Sensors/CM4_TEMP_A0: R41.1, U9.7 (A0)
/CM4/Sensors/CM4_TEMP_A1: R42.1, U9.6 (A1)
/CM4/Sensors/CM4_TEMP_A2: R43.1, U9.5 (A2)
/CM4/Sensors/M.2_TEMP_A0: R46.1, U11.7 (A0)
/CM4/Sensors/M.2_TEMP_A1: R47.1, U11.6 (A1)
/CM4/Sensors/M.2_TEMP_A2: R48.1, U11.5 (A2)
GND: C15.2, C16.2, C17.2, C18.2, C19.2, C20.2, C21.2, C22.2, R41.2, R42.2, R43.2, R44.2, R45.2, R47.2, R48.2, U9.4 (GND), U9.9 (ePAD), U10.10 (GND), U11.4 (GND), U11.9 (ePAD); also elsewhere on the board
unnamed: C19.1, J5.2, R44.1, U10.2 (AINP_AIN0)
unnamed: C20.1, J6.2, R45.1, U10.3 (AINM_AIN1)
unnamed: R40.2, U10.6 (~ALERT)

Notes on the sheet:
Temperature monitoring via I2C (place under or near M.2)
I2C base address??? + 0x0
FIXME
I2C base address??? + 0x1
Sensors
I2C 0x18
(cooling loop, etc)
2x headers for 10K NTC thermistors
Temperature monitoring via I2C (place under or near CM4)

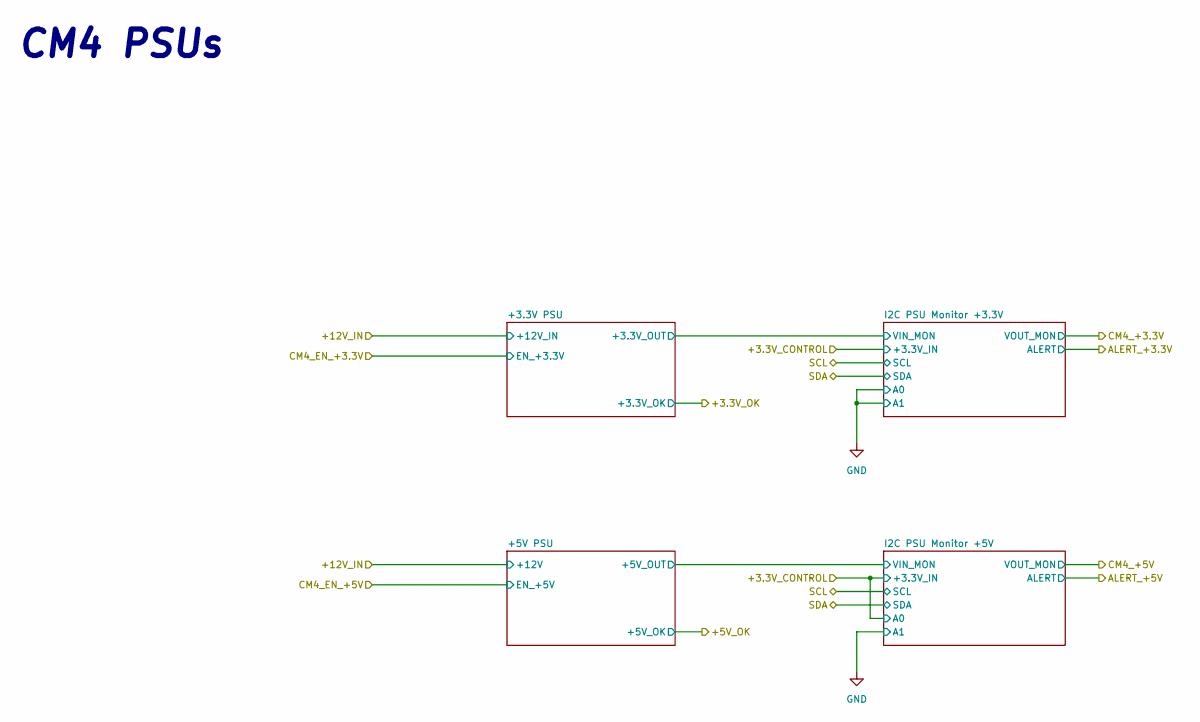
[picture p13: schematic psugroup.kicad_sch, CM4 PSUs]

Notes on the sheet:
CM4 PSUs

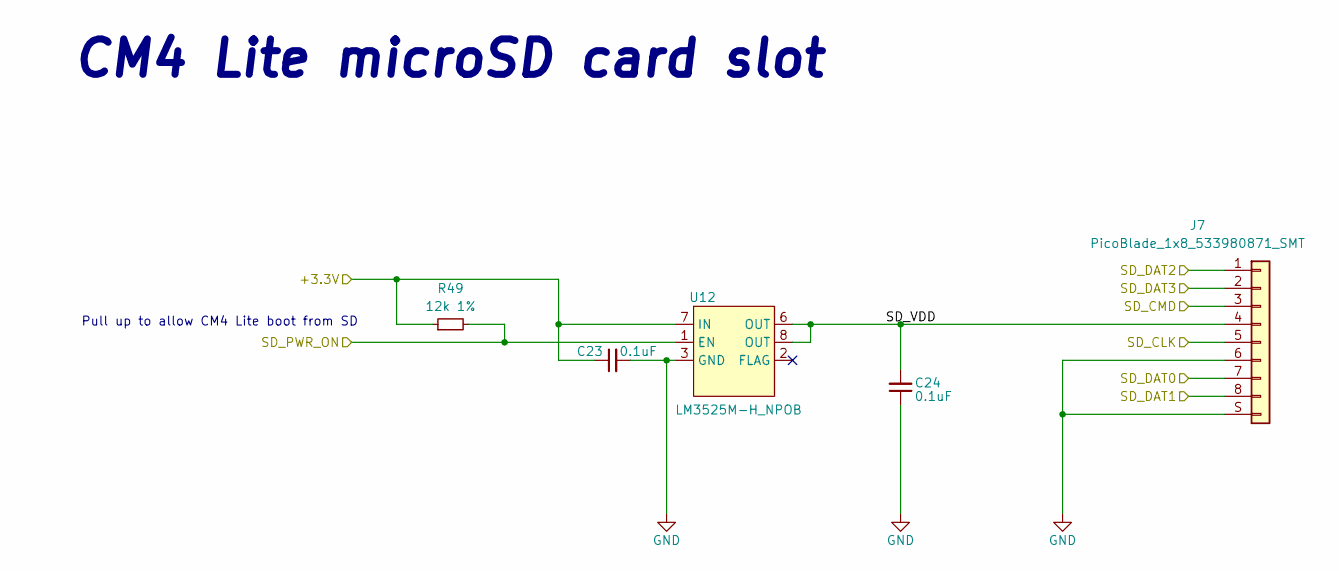
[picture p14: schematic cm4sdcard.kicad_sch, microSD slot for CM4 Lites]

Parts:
C23, C24: 0.1uF; C_0805_2012Metric; Part Description 10uF 10% 10V Ceramic Capacitor X7R 0805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
J7: PicoBlade_1x8_533980871_SMT; MOLEX_533980871; MPN 533980871
R49: 12k 1%; R_0402_1005Metric
U12: LM3525M-H_NPOB; SOIC-8_3.9x4.9mm_P1.27mm; MPN LM3525M-H/NPOB

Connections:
/CM4/CM4_+3.3V: C23.1, R49.1, U12.7 (IN); also elsewhere on the board
/CM4/SD_CLK: J7.5; also elsewhere on the board
/CM4/SD_CMD: J7.3; also elsewhere on the board
/CM4/SD_DAT0: J7.7; also elsewhere on the board
/CM4/SD_DAT1: J7.8; also elsewhere on the board
/CM4/SD_DAT2: J7.1; also elsewhere on the board
/CM4/SD_DAT3: J7.2; also elsewhere on the board
/CM4/SD_PWR_ON: R49.2, U12.1 (EN); also elsewhere on the board
/CM4/micro SD card/SD_VDD: C24.2, J7.4, U12.6 (OUT), U12.8 (OUT)
GND: C23.2, C24.1, J7.6, J7.S (SHIELD), U12.3 (GND); also elsewhere on the board

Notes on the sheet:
CM4 Lite microSD card slot
Pull up to allow CM4 Lite boot from SD


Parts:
CM1: ComputeModule4-CM4; Raspberry-Pi-4-Compute-Module_outline; MPN 2x DF40C-100DS-0.4V; Digi-Key_PN 2x H11615CT-ND

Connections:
/CM4/CM4 Hirose connectors/GPIO2: CM1.58 (GPIO2); also elsewhere on the board
/CM4/CM4 Hirose connectors/GPIO3: CM1.56 (GPIO3); also elsewhere on the board
/CM4/CM4 Hirose connectors/GPIO4: CM1.54 (GPIO4); also elsewhere on the board
/CM4/CM4 Hirose connectors/GPIO5: CM1.34 (GPIO5); also elsewhere on the board
/CM4/CM4 Hirose connectors/GPIO6: CM1.30 (GPIO6); also elsewhere on the board
/CM4/CM4 Hirose connectors/GPIO7: CM1.37 (GPIO7); also elsewhere on the board
/CM4/CM4 Hirose connectors/GPIO8: CM1.39 (GPIO8); also elsewhere on the board
/CM4/CM4 Hirose connectors/GPIO9: CM1.40 (GPIO9); also elsewhere on the board
/CM4/CM4 Hirose connectors/GPIO10: CM1.44 (GPIO10); also elsewhere on the board
/CM4/CM4 Hirose connectors/GPIO11: CM1.38 (GPIO11); also elsewhere on the board
/CM4/CM4 Hirose connectors/GPIO12: CM1.31 (GPIO12); also elsewhere on the board
/CM4/CM4 Hirose connectors/GPIO13: CM1.28 (GPIO13); also elsewhere on the board
/CM4/CM4 Hirose connectors/GPIO18: CM1.49 (GPIO18); also elsewhere on the board
/CM4/CM4 Hirose connectors/GPIO19: CM1.26 (GPIO19); also elsewhere on the board
/CM4/CM4 Hirose connectors/GPIO20: CM1.27 (GPIO20); also elsewhere on the board
/CM4/CM4 Hirose connectors/GPIO21: CM1.25 (GPIO21); also elsewhere on the board
/CM4/CM4 Hirose connectors/GPIO22: CM1.46 (GPIO22); also elsewhere on the board
/CM4/CM4 Hirose connectors/ID_SC: CM1.35 (ID_SC); also elsewhere on the board
/CM4/CM4 Hirose connectors/ID_SD: CM1.36 (ID_SD); also elsewhere on the board
/CM4/CM4 Hirose connectors/~EXTRST: CM1.100 (nEXTRST); also elsewhere on the board
/CM4/CM4_+5V: CM1.77 (+5v_(Input)), CM1.79 (+5v_(Input)), CM1.81 (+5v_(Input)), CM1.83 (+5v_(Input)), CM1.85 (+5v_(Input)), CM1.87 (+5v_(Input)); also elsewhere on the board
/CM4/CM4_I2C_SCL: CM1.80 (SCL0); also elsewhere on the board
/CM4/CM4_I2C_SDA: CM1.82 (SDA0); also elsewhere on the board
/CM4/CM4_OUT_+1.8V: CM1.88 (+1.8v_(Output)), CM1.90 (+1.8v_(Output)); also elsewhere on the board
/CM4/CM4_OUT_+3.3V: CM1.78 (GPIO_VREF(1.8v/3.3v_Input)), CM1.84 (+3.3v_(Output)), CM1.86 (+3.3v_(Output)); also elsewhere on the board
/CM4/HDMICEC: CM1.151 (HDMI0_CEC); also elsewhere on the board
/CM4/HDMICK+: CM1.188 (HDMI0_CLK_P); also elsewhere on the board
/CM4/HDMICK-: CM1.190 (HDMI0_CLK_N); also elsewhere on the board
/CM4/HDMID0+: CM1.182 (HDMI0_TX0_P); also elsewhere on the board
/CM4/HDMID0-: CM1.184 (HDMI0_TX0_N); also elsewhere on the board
/CM4/HDMID1+: CM1.176 (HDMI0_TX1_P); also elsewhere on the board
/CM4/HDMID1-: CM1.178 (HDMI0_TX1_N); also elsewhere on the board
/CM4/HDMID2+: CM1.170 (HDMI0_TX2_P); also elsewhere on the board
/CM4/HDMID2-: CM1.172 (HDMI0_TX2_N); also elsewhere on the board
/CM4/HDMIHP: CM1.153 (HDMI0_HOTPLUG); also elsewhere on the board
/CM4/HDMISCL: CM1.200 (HDMI0_SCL); also elsewhere on the board
/CM4/HDMISDA: CM1.199 (HDMI0_SDA); also elsewhere on the board
/CM4/I2C_GLOBAL_EN: CM1.99 (Global_EN); also elsewhere on the board
/CM4/I2C_RUN_PG: CM1.92 (RUN_PG); also elsewhere on the board
/CM4/PCIE_CLK+: CM1.110 (PCIe_CLK_P); also elsewhere on the board
/CM4/PCIE_CLK-: CM1.112 (PCIe_CLK_N); also elsewhere on the board
/CM4/PCIE_RX+: CM1.116 (PCIe_RX_P); also elsewhere on the board
/CM4/PCIE_RX-: CM1.118 (PCIe_RX_N); also elsewhere on the board
/CM4/PCIE_TX+: CM1.122 (PCIe_TX_P); also elsewhere on the board
/CM4/PCIE_TX-: CM1.124 (PCIe_TX_N); also elsewhere on the board
/CM4/SD_CLK: CM1.57 (SD_CLK); also elsewhere on the board
/CM4/SD_CMD: CM1.62 (SD_CMD); also elsewhere on the board
/CM4/SD_DAT0: CM1.63 (SD_DAT0); also elsewhere on the board
/CM4/SD_DAT1: CM1.67 (SD_DAT1); also elsewhere on the board
/CM4/SD_DAT2: CM1.69 (SD_DAT2); also elsewhere on the board
/CM4/SD_DAT3: CM1.61 (SD_DAT3); also elsewhere on the board
/CM4/SD_PWR_ON: CM1.75 (SD_PWR_ON); also elsewhere on the board
/CM4/SOFT_HALT: CM1.24 (GPIO26); also elsewhere on the board
/CM4/SOFT_REBOOT: CM1.48 (GPIO27); also elsewhere on the board
/CM4/USB+: CM1.105 (USB2_P); also elsewhere on the board
/CM4/USB-: CM1.103 (USB2_N); also elsewhere on the board
/CM4/USBOTG: CM1.101 (USB_OTG_ID); also elsewhere on the board
/CM4/~EthLED1: CM1.19 (Ethernet_nLED1(3.3v)); also elsewhere on the board
/CM4/~EthLED2: CM1.17 (Ethernet_nLED2(3.3v)); also elsewhere on the board
/CM4/~EthLED3: CM1.15 (Ethernet_nLED3(3.3v)); also elsewhere on the board
/CM4/~I2C_RPI_BOOT: CM1.93 (nRPIBOOT); also elsewhere on the board
/CM4/~INT_CM4: CM1.47 (GPIO23); also elsewhere on the board
/CM4/~PANIC_CM4: CM1.45 (GPIO24); also elsewhere on the board
/CM4/~PCIE_CLK_REQ: CM1.102 (PCIe_CLK_nREQ); also elsewhere on the board
/CM4/~PCIE_RST: CM1.109 (PCIe_nRST); also elsewhere on the board
/CM4/~PI_Activity: CM1.21 (PI_nLED_Activity); also elsewhere on the board
/CM4/~PWR_LED: CM1.95 (nPI_LED_PWR); also elsewhere on the board
/EthA+: CM1.12 (Ethernet_Pair0_P); also elsewhere on the board
/EthA-: CM1.10 (Ethernet_Pair0_N); also elsewhere on the board
/EthB+: CM1.4 (Ethernet_Pair1_P); also elsewhere on the board
/EthB-: CM1.6 (Ethernet_Pair1_N); also elsewhere on the board
/EthC+: CM1.11 (Ethernet_Pair2_P); also elsewhere on the board
/EthC-: CM1.9 (Ethernet_Pair2_N); also elsewhere on the board
/EthD+: CM1.3 (Ethernet_Pair3_P); also elsewhere on the board
/EthD-: CM1.5 (Ethernet_Pair3_N); also elsewhere on the board
/UART_CTS1: CM1.29 (GPIO16); also elsewhere on the board
/UART_RTS1: CM1.50 (GPIO17); also elsewhere on the board
/UART_RXD1: CM1.51 (GPIO15); also elsewhere on the board
/UART_TXD1: CM1.55 (GPIO14); also elsewhere on the board
/~I2C_RESET: CM1.41 (GPIO25); also elsewhere on the board
GND: CM1.1 (GND), CM1.2 (GND), CM1.7 (GND), CM1.8 (GND), CM1.13 (GND), CM1.14 (GND), CM1.22 (GND), CM1.23 (GND), CM1.32 (GND), CM1.33 (GND), CM1.42 (GND), CM1.43 (GND), CM1.52 (GND), CM1.53 (GND), CM1.59 (GND), CM1.60 (GND), CM1.65 (GND), CM1.66 (GND), CM1.71 (GND), CM1.74 (GND), CM1.89 (WiFi_nDisable), CM1.91 (BT_nDisable), CM1.98 (GND), CM1.107 (GND), CM1.108 (GND), CM1.113 (GND), CM1.114 (GND), CM1.119 (GND), CM1.120 (GND), CM1.125 (GND), CM1.126 (GND), CM1.131 (GND), CM1.132 (GND), CM1.137 (GND), CM1.138 (GND), CM1.144 (GND), CM1.150 (GND), CM1.155 (GND), CM1.156 (GND), CM1.161 (GND), CM1.162 (GND), CM1.167 (GND), CM1.168 (GND), CM1.173 (GND), CM1.174 (GND), CM1.179 (GND), CM1.180 (GND), CM1.185 (GND), CM1.186 (GND), CM1.191 (GND), CM1.192 (GND), CM1.197 (GND), CM1.198 (GND); also elsewhere on the board

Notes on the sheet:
OK to swap for routing
Hw PWM
OK to float, no voltage selection for SD
Disabled, pulled to ground.
Pulling Global_EN low amounts to a hard reset.
OK to float, internal PU
GPIO Voltage select nailed to +3.3V to avoid confusion over I2C bus voltage pull-up

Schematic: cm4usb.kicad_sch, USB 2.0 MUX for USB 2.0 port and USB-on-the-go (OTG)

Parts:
C25: 1uF; C_0402_1005Metric
C26: 0.1uF; C_0402_1005Metric
C27, C29, C30, C31, C32: 10uF; C_0805_2012Metric; Part Description 10uF 10% 10V Ceramic Capacitor X7R 0805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
C28: 100uF; C_1210_3225Metric
J8, J9: PicoBlade_1x6_533980671_SMT; MOLEX_533980671; MPN 533980771
R50, R54: 5.1k; R_0402_1005Metric
R51, R52: 2.2K 1%; R_0402_1005Metric; Part Description Resistor 12K M1005 1% 63mW
R53: 330R; R_0402_1005Metric; Part Description Resistor 1K M1005 1% 63mW
R55: 10k; R_0402_1005Metric
R56: 15k 1%; R_0402_1005Metric; Part Description Resistor 15K M1005 1% 63mW
U13: USB3740B-AI2; Microchip_UQFN-10_1.3x1.8mm_P0.4mm_pin1; MPN USB3740B-AI2
U14: AP22653FDZ-7; Diodes_W-DFN2020-6_A1; MPN AP22653FDZ-7

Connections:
/CM4/CM4_+3.3V: C25.1, C26.1, U13.5 (VDD); also elsewhere on the board
/CM4/CM4_+5V: C27.1, R55.2, U14.1 (IN), U14.3 (EN); also elsewhere on the board
/CM4/LED_USB_OTG_CONN: R53.1; also elsewhere on the board
/CM4/USB 2.0 MUX/HD1+: J8.3, U13.2 (DP_1)
/CM4/USB 2.0 MUX/HD1-: J8.4, U13.1 (DM_1)
/CM4/USB 2.0 MUX/HD_OTG+: J9.3, U13.6 (DP_2)
/CM4/USB 2.0 MUX/HD_OTG-: J9.4, U13.7 (DM_2)
/CM4/USB 2.0 MUX/USB1_CC1: J8.6, R50.1
/CM4/USB 2.0 MUX/USB2_CC1: J9.6, R54.1
/CM4/USB 2.0 MUX/VBUS1: C28.1, C29.1, C30.1, C31.1, C32.1, J8.1, U14.6 (OUT)
/CM4/USB 2.0 MUX/VBUS_OTG: J9.1, R51.1, R53.2
/CM4/USB+: U13.10 (DP); also elsewhere on the board
/CM4/USB-: U13.9 (DM); also elsewhere on the board
/CM4/USBOTG: R51.2, R52.1, U13.4 (S); also elsewhere on the board
GND: C25.2, C26.2, C27.2, C28.2, C29.2, C30.2, C31.2, C32.2, J8.2, J8.5, J8.S (SHIELD), J9.2, J9.5, J9.S (SHIELD), R50.2, R52.2, R54.2, R56.2, U13.3 (~OE), U13.8 (GND), U14.2 (GND); also elsewhere on the board
unnamed: R55.1, U14.4 (~FAULT)
unnamed: R56.1, U14.5 (ILIM)

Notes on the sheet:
- USB-C A5 (CC) 56K 5% resistor to VBUS - USB B6, B7 not present - A6/A7 carry DP - All VBUS pins connected (A4, B4, A9, B9) - All GND pins connected (A1, B1, A12, B12)
USB 2.0 over USB-C routing:
Always low (high disables)
Source:
Current Limit switch for port 1
USB 2.0 MUX for USB 2.0 port and USB-on-the-go (OTG)
#OTG
USB 2.0 MUX for OTG (w/ ESD)
If a cable is plugged into the UTG USB-C port, USB-C port is bypassed and CM4 acts as a USB device (VBUS_UTG high) Source: Truth table 4-1 in USB3840 datasheet ESD protection provided on all DM/DP pins.
Figure 3-23 and Table 3-13 in USB 3.1 specification
USB-C CM4-as-device (OTG) with USB 2.0 signals
S = low
USB-C connector with USB 2.0 signals
S = high

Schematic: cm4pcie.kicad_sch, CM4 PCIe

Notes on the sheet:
PCIe
PCIe x1 draws maximum of +3.3V @ 3A, use separate power supply if needed
Intentionally left blank when PCIe switch removed.
TX and RX can have PN swaps to improve routing

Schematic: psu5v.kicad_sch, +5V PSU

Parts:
C49, C50, C51, C52, C53, C54: 10uF 35V; C_1206_3216Metric; MPN GRT31CC8YA106KE01L
C55, C56: 0.1uF; C_0402_1005Metric; MPN CGA2B1X7R1C104K050BC
C57: DNP; C_0402_1005Metric
C58: 1.2nF; C_0402_1005Metric; Part Description 1200pF 10% 10V Ceramic Capacitor X5R 04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
C59: DNP; C_0402_1005Metric; Part Description 220 pF, 50 V, 0402 [1005 Metric], ± 5%,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
C60, C61, C62, C63: 10uF; C_0805_2012Metric; MPN LMK212B7106KG-TD
C64: 100uF; CP_EIA-7343-31_Kemet-D; MPN T495D107K006ATE130
L2: SRN6045TA-3R3Y; L_Bourns_SRN6045TA; Part Description 3.3µH Semi-Shielded Wirewound Inductor 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
R62: 10R; R_0402_1005Metric; Part Description Resistor 10R M1005 1% 63mW
R63: 20k 1%; R_0402_1005Metric; MPN AC0402FR-0720KL
R64: 12k 1%; R_0402_1005Metric; MPN AC0402FR-0712KL
R65: 2.2K 1%; R_0402_1005Metric; MPN AC0402FR-072K2L
R66: 600R; R_0402_1005Metric
TP13, TP14: TestPoint; TestPoint_Pad_D1.0mm
U16: AP64501SP-13; SOIC-8-1EP_3.9x4.9mm_P1.27mm_EP2.95x4.9mm_Mask2.71x3.4mm_Th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; MPN AP64501SP-13

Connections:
+3.3V: C49.1, C50.1, C51.1, C52.1, C53.1, C54.1, U16.2 (VIN); also elsewhere on the board
/CM4/CM4 PSU/+5V PSU/+5V_OUT: C60.1, C61.1, C62.1, C63.1, C64.1, L2.2, R64.1, R66.1, TP13.1; also elsewhere on the board
/CM4/CM4_EN_+5V: U16.3 (EN); also elsewhere on the board
/CM4/LED_+5V_OK_CONN: R66.2; also elsewhere on the board
GND: C49.2, C50.2, C51.2, C52.2, C53.2, C54.2, C56.2, C58.2, C60.2, C61.2, C62.2, C63.2, C64.2, R65.2, TP14.1, U16.7 (GND), U16.9 (EP); also elsewhere on the board
unnamed: C55.1, R62.2
unnamed: C55.2, U16.1 (BST)
unnamed: C56.1, U16.4 (SS)
unnamed: C58.1, R63.2
unnamed: L2.1, R62.1, U16.8 (SW)
unnamed: R63.1, U16.6 (COMP)
unnamed: R64.2, R65.1, U16.5 (FB)

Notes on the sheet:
< PSU On LED
+5V PSU @ 3A peak
+5v @ 3A PSU ( 7.5v-28v Input )
NB: Borrowed/Inspired by Raspberry Pi Foundation's CM4IO
NB: Use GND testpoint from 3.3V PSU

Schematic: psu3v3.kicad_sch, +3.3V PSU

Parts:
C33, C34, C35, C36, C37, C38: 10uF 35V; C_1206_3216Metric; MPN GRT31CC8YA106KE01L
C39, C40: 0.1uF; C_0402_1005Metric; MPN CGA2B1X7R1C104K050BC
C41, C43: DNP; C_0402_1005Metric
C42: 1.2nF; C_0402_1005Metric; MPN GCM155R71H122KA37D
C44, C45, C46, C47: 10uF; C_0805_2012Metric; MPN LMK212B7106KG-TD
C48: 100uF; CP_EIA-7343-31_Kemet-D; MPN T495D107K006ATE130
L1: SRN6045TA-3R3Y; L_Bourns_SRN6045TA; MPN SRN6045TA-3R3Y
R57: 10R; R_0402_1005Metric; MPN AC0402FR-0710RL
R58: 12k 1%; R_0402_1005Metric; MPN AC0402FR-0712KL
R59: 47k 1%; R_0402_1005Metric; MPN RC0402FR-0747KL
R60: 15k 1%; R_0402_1005Metric; MPN AC0402FR-0715KL
R61: 260R; R_0402_1005Metric
TP11, TP12: TestPoint; TestPoint_Pad_D1.0mm
U15: AP64501SP-13; SOIC-8-1EP_3.9x4.9mm_P1.27mm_EP2.95x4.9mm_Mask2.71x3.4mm_Th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; MPN AP64501SP-13

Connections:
+3.3V: C33.1, C34.1, C35.1, C36.1, C37.1, C38.1, U15.2 (VIN); also elsewhere on the board
/CM4/CM4 PSU/+3.3V PSU/+3.3V_OUT: C44.1, C45.1, C46.1, C47.1, C48.1, L1.2, R59.1, R61.1, TP12.1; also elsewhere on the board
/CM4/CM4_EN_+3.3V: U15.3 (EN); also elsewhere on the board
/CM4/LED_+3.3V_OK_CONN: R61.2; also elsewhere on the board
GND: C33.2, C34.2, C35.2, C36.2, C37.2, C38.2, C40.2, C42.2, C44.2, C45.2, C46.2, C47.2, C48.2, R60.2, TP11.1, U15.7 (GND), U15.9 (EP); also elsewhere on the board
unnamed: C39.1, R57.2
unnamed: C39.2, U15.1 (BST)
unnamed: C40.1, U15.4 (SS)
unnamed: C42.1, R58.2
unnamed: L1.1, R57.1, U15.8 (SW)
unnamed: R58.1, U15.6 (COMP)
unnamed: R59.2, R60.1, U15.5 (FB)

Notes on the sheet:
NB: Borrowed/Inspired by Raspberry Pi Foundation's CM4IO
3.3v @ 3.3A PSU for PCIe Only ( 12v Input )
+3.3V PSU @ 3A peak
< PSU On LED

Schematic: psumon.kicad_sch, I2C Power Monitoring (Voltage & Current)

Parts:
C13: 10uF; C_0402_1005Metric
C14: 0.1uF; C_0402_1005Metric
TP10: TestPoint; TestPoint_Pad_D1.0mm
U8: INA260; TSSOP-16_4.4x5mm_P0.65mm_pin1; MPN INA260AIPW

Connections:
+12V: C13.1, C14.1, U8.10 (VS); also elsewhere on the board
/CM4/CM4 PSU/+3.3V PSU/+3.3V_OUT: U8.1 (IN+), U8.2 (IN+), U8.3 (IN+), U8.12 (VBUS); also elsewhere on the board
/CM4/CM4_+3.3V: TP10.1, U8.14 (IN-), U8.15 (IN-), U8.16 (IN-); also elsewhere on the board
/CM4/CM4_ALERT_+3.3V: U8.7 (ALERT); also elsewhere on the board
/CM4/I2C_SCL: U8.9 (SCL); also elsewhere on the board
/CM4/I2C_SDA: U8.8 (SDA); also elsewhere on the board
GND: C13.2, C14.2, U8.4 (A1), U8.5 (A0), U8.6 (GND), U8.11 (GND); also elsewhere on the board

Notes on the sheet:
Voltage & Current
I2C Power Monitoring

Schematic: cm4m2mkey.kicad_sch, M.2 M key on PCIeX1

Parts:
C65, C66, C67: 10uF; C_0402_1005Metric
C68, C69: 1uF; C_0402_1005Metric
C70, C71, C72, C73, C74: 10nF; C_0402_1005Metric
C75: 0.1uF; C_0402_1005Metric
J10: 1-2199119-6; 1-2199119-6_2280_standoff_nooutline
R67, R68, R69, R70, R71, R72, R73, R74, R75, R76, R77, R78, R79, R80: 50R; R_0402_1005Metric

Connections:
/CM4/CM4_+3.3V: C65.1, C66.1, C67.1, C68.1, C69.1, C70.1, C71.1, C72.1, C73.1, C74.1, C75.1, J10.2 (3.3V), J10.4 (3.3V), J10.12 (3.3V), J10.14 (3.3V), J10.16 (3.3V), J10.18 (3.3V), J10.70 (3.3V), J10.72 (3.3V), J10.74 (3.3V); also elsewhere on the board
/CM4/M2_1_ACTIVITY_LED: J10.10 (DAS/DSS); also elsewhere on the board
/CM4/PCIE_CLK+: J10.55 (REFCLK+), R68.1; also elsewhere on the board
/CM4/PCIE_CLK-: J10.53 (REFCLK-), R67.1; also elsewhere on the board
/CM4/PCIE_RX+: J10.43 (PER0+); also elsewhere on the board
/CM4/PCIE_RX-: J10.41 (PER0-); also elsewhere on the board
/CM4/PCIE_TX+: J10.47 (PET0-); also elsewhere on the board
/CM4/PCIE_TX-: J10.49 (PET0+); also elsewhere on the board
/CM4/~PCIE_CLK_REQ: J10.52 (~CLKREQ); also elsewhere on the board
/CM4/~PCIE_RST: J10.50 (~PERST); also elsewhere on the board
GND: C65.2, C66.2, C67.2, C68.2, C69.2, C70.2, C71.2, C72.2, C73.2, C74.2, C75.2, J10.1 (GND), J10.3 (GND), J10.9 (GND), J10.15 (GND), J10.21 (GND), J10.27 (GND), J10.33 (GND), J10.39 (GND), J10.45 (GND), J10.51 (GND), J10.57 (GND), J10.71 (GND), J10.73 (GND), J10.75 (GND), J10.S (SHIELD), R67.2, R68.2, R69.1, R70.1, R71.1, R72.1, R73.1, R74.1, R75.1, R76.1, R77.1, R78.1, R79.1, R80.1; also elsewhere on the board
unnamed 152: J10.5 (PER3-), R69.2; also elsewhere on the board
unnamed 153: J10.7 (PER+), R70.2; also elsewhere on the board
unnamed 154: J10.11 (PET3-), R71.2; also elsewhere on the board
unnamed 155: J10.13 (PET3+), R72.2; also elsewhere on the board
unnamed 156: J10.17 (PER2-), R73.2; also elsewhere on the board
unnamed 157: J10.19 (PER2+), R74.2; also elsewhere on the board
unnamed 158: J10.23 (PET2-), R75.2; also elsewhere on the board
unnamed 159: J10.25 (PET2+), R76.2; also elsewhere on the board
unnamed 160: J10.29 (PER1-), R77.2; also elsewhere on the board
unnamed 161: J10.31 (PER1+), R78.2; also elsewhere on the board
unnamed 162: J10.35 (PET1-), R79.2; also elsewhere on the board
unnamed 163: J10.37 (PET1+), R80.2; also elsewhere on the board

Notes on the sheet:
90Ω Differential Pair
H or NC = PCIe
M.2 M key on PCIeX1
TX and RX can have PN swaps to improve routing
PCIe x1 draws maximum of +3.3V @ 3A, use separate power supply if needed
(instead of SATA)

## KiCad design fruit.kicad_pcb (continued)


Board: 4 copper layers, 167.0 x 100.0 mm, 206 parts (1 on the bottom side), 180 nets.

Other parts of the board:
C1: 10uF; C_0402_1005Metric
C2: 0.1uF; C_0402_1005Metric
CM1#2: ComputeModule4-CM4; Raspberry-Pi-4-Compute-Module_outline
COOLER1#2: 53-61mm_NorthBridge_45deg_arms
J10#2: 1-2199119-6; 1-2199119-6_2280_standoff_nooutline
TP1: TestPoint; TestPoint_Pad_D1.0mm
U1: INA260; TSSOP-16_4.4x5mm_P0.65mm_pin1
kibuzzard-61E49B53: G***; kibuzzard-61E49B53
kibuzzard-61E484E1: G***; kibuzzard-61E484E1

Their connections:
+12V: C1.1, C2.1, U1.5 (A0), U1.10 (VS); also elsewhere on the board
/CM4/CM4 Hirose connectors/GPIO2: CM1#2.58 (GPIO2); also elsewhere on the board
/CM4/CM4 Hirose connectors/GPIO3: CM1#2.56 (GPIO3); also elsewhere on the board
/CM4/CM4 Hirose connectors/GPIO4: CM1#2.54 (GPIO4); also elsewhere on the board
/CM4/CM4 Hirose connectors/GPIO5: CM1#2.34 (GPIO5); also elsewhere on the board
/CM4/CM4 Hirose connectors/GPIO6: CM1#2.30 (GPIO6); also elsewhere on the board
/CM4/CM4 Hirose connectors/GPIO7: CM1#2.37 (GPIO7); also elsewhere on the board
/CM4/CM4 Hirose connectors/GPIO8: CM1#2.39 (GPIO8); also elsewhere on the board
/CM4/CM4 Hirose connectors/GPIO9: CM1#2.40 (GPIO9); also elsewhere on the board
/CM4/CM4 Hirose connectors/GPIO10: CM1#2.44 (GPIO10); also elsewhere on the board
/CM4/CM4 Hirose connectors/GPIO11: CM1#2.38 (GPIO11); also elsewhere on the board
/CM4/CM4 Hirose connectors/GPIO12: CM1#2.31 (GPIO12); also elsewhere on the board
/CM4/CM4 Hirose connectors/GPIO13: CM1#2.28 (GPIO13); also elsewhere on the board
/CM4/CM4 Hirose connectors/GPIO18: CM1#2.49 (GPIO18); also elsewhere on the board
/CM4/CM4 Hirose connectors/GPIO19: CM1#2.26 (GPIO19); also elsewhere on the board
/CM4/CM4 Hirose connectors/GPIO20: CM1#2.27 (GPIO20); also elsewhere on the board
/CM4/CM4 Hirose connectors/GPIO21: CM1#2.25 (GPIO21); also elsewhere on the board
/CM4/CM4 Hirose connectors/GPIO22: CM1#2.46 (GPIO22); also elsewhere on the board
/CM4/CM4 Hirose connectors/ID_SC: CM1#2.35 (ID_SC); also elsewhere on the board
/CM4/CM4 Hirose connectors/ID_SD: CM1#2.36 (ID_SD); also elsewhere on the board
/CM4/CM4 Hirose connectors/~EXTRST: CM1#2.100 (nEXTRST); also elsewhere on the board
/CM4/CM4 PSU/+5V PSU/+5V_OUT: U1.1 (IN+), U1.2 (IN+), U1.3 (IN+), U1.12 (VBUS); also elsewhere on the board
/CM4/CM4_+3.3V: J10#2.2 (3.3V), J10#2.4 (3.3V), J10#2.12 (3.3V), J10#2.14 (3.3V), J10#2.16 (3.3V), J10#2.18 (3.3V), J10#2.70 (3.3V), J10#2.72 (3.3V), J10#2.74 (3.3V); also elsewhere on the board
/CM4/CM4_+5V: CM1#2.77 (+5v_(Input)), CM1#2.79 (+5v_(Input)), CM1#2.81 (+5v_(Input)), CM1#2.83 (+5v_(Input)), CM1#2.85 (+5v_(Input)), CM1#2.87 (+5v_(Input)), TP1.1, U1.14 (IN-), U1.15 (IN-), U1.16 (IN-); also elsewhere on the board
/CM4/CM4_ALERT_+5V: U1.7 (ALERT); also elsewhere on the board
/CM4/CM4_I2C_SCL: CM1#2.80 (SCL0); also elsewhere on the board
/CM4/CM4_I2C_SDA: CM1#2.82 (SDA0); also elsewhere on the board
/CM4/CM4_OUT_+1.8V: CM1#2.88 (+1.8v_(Output)), CM1#2.90 (+1.8v_(Output)); also elsewhere on the board
/CM4/CM4_OUT_+3.3V: CM1#2.78 (GPIO_VREF(1.8v/3.3v_Input)), CM1#2.84 (+3.3v_(Output)), CM1#2.86 (+3.3v_(Output)); also elsewhere on the board
/CM4/HDMICEC: CM1#2.151 (HDMI0_CEC); also elsewhere on the board
/CM4/HDMICK+: CM1#2.188 (HDMI0_CLK_P); also elsewhere on the board
/CM4/HDMICK-: CM1#2.190 (HDMI0_CLK_N); also elsewhere on the board
/CM4/HDMID0+: CM1#2.182 (HDMI0_TX0_P); also elsewhere on the board
/CM4/HDMID0-: CM1#2.184 (HDMI0_TX0_N); also elsewhere on the board
/CM4/HDMID1+: CM1#2.176 (HDMI0_TX1_P); also elsewhere on the board
/CM4/HDMID1-: CM1#2.178 (HDMI0_TX1_N); also elsewhere on the board
/CM4/HDMID2+: CM1#2.170 (HDMI0_TX2_P); also elsewhere on the board
/CM4/HDMID2-: CM1#2.172 (HDMI0_TX2_N); also elsewhere on the board
/CM4/HDMIHP: CM1#2.153 (HDMI0_HOTPLUG); also elsewhere on the board
/CM4/HDMISCL: CM1#2.200 (HDMI0_SCL); also elsewhere on the board
/CM4/HDMISDA: CM1#2.199 (HDMI0_SDA); also elsewhere on the board
/CM4/I2C_GLOBAL_EN: CM1#2.99 (Global_EN); also elsewhere on the board
/CM4/I2C_RUN_PG: CM1#2.92 (RUN_PG); also elsewhere on the board
/CM4/I2C_SCL: U1.9 (SCL); also elsewhere on the board
/CM4/I2C_SDA: U1.8 (SDA); also elsewhere on the board
/CM4/M2_1_ACTIVITY_LED: J10#2.10 (DAS/DSS); also elsewhere on the board
/CM4/PCIE_CLK+: CM1#2.110 (PCIe_CLK_P), J10#2.55 (REFCLK+); also elsewhere on the board
/CM4/PCIE_CLK-: CM1#2.112 (PCIe_CLK_N), J10#2.53 (REFCLK-); also elsewhere on the board
/CM4/PCIE_RX+: CM1#2.116 (PCIe_RX_P), J10#2.43 (PER0+); also elsewhere on the board
/CM4/PCIE_RX-: CM1#2.118 (PCIe_RX_N), J10#2.41 (PER0-); also elsewhere on the board
/CM4/PCIE_TX+: CM1#2.122 (PCIe_TX_P), J10#2.47 (PET0-); also elsewhere on the board
/CM4/PCIE_TX-: CM1#2.124 (PCIe_TX_N), J10#2.49 (PET0+); also elsewhere on the board
/CM4/SD_CLK: CM1#2.57 (SD_CLK); also elsewhere on the board
/CM4/SD_CMD: CM1#2.62 (SD_CMD); also elsewhere on the board
/CM4/SD_DAT0: CM1#2.63 (SD_DAT0); also elsewhere on the board
/CM4/SD_DAT1: CM1#2.67 (SD_DAT1); also elsewhere on the board
/CM4/SD_DAT2: CM1#2.69 (SD_DAT2); also elsewhere on the board
/CM4/SD_DAT3: CM1#2.61 (SD_DAT3); also elsewhere on the board
/CM4/SD_PWR_ON: CM1#2.75 (SD_PWR_ON); also elsewhere on the board
/CM4/SOFT_HALT: CM1#2.24 (GPIO26); also elsewhere on the board
/CM4/SOFT_REBOOT: CM1#2.48 (GPIO27); also elsewhere on the board
/CM4/USB+: CM1#2.105 (USB2_P); also elsewhere on the board
/CM4/USB-: CM1#2.103 (USB2_N); also elsewhere on the board
/CM4/USBOTG: CM1#2.101 (USB_OTG_ID); also elsewhere on the board
/CM4/~EthLED1: CM1#2.19 (Ethernet_nLED1(3.3v)); also elsewhere on the board
/CM4/~EthLED2: CM1#2.17 (Ethernet_nLED2(3.3v)); also elsewhere on the board
/CM4/~EthLED3: CM1#2.15 (Ethernet_nLED3(3.3v)); also elsewhere on the board
/CM4/~I2C_RPI_BOOT: CM1#2.93 (nRPIBOOT); also elsewhere on the board
/CM4/~INT_CM4: CM1#2.47 (GPIO23); also elsewhere on the board
/CM4/~PANIC_CM4: CM1#2.45 (GPIO24); also elsewhere on the board
/CM4/~PCIE_CLK_REQ: CM1#2.102 (PCIe_CLK_nREQ), J10#2.52 (~CLKREQ); also elsewhere on the board
/CM4/~PCIE_RST: CM1#2.109 (PCIe_nRST), J10#2.50 (~PERST); also elsewhere on the board
/CM4/~PI_Activity: CM1#2.21 (PI_nLED_Activity); also elsewhere on the board
/CM4/~PWR_LED: CM1#2.95 (nPI_LED_PWR); also elsewhere on the board
/EthA+: CM1#2.12 (Ethernet_Pair0_P); also elsewhere on the board
/EthA-: CM1#2.10 (Ethernet_Pair0_N); also elsewhere on the board
/EthB+: CM1#2.4 (Ethernet_Pair1_P); also elsewhere on the board
/EthB-: CM1#2.6 (Ethernet_Pair1_N); also elsewhere on the board
/EthC+: CM1#2.11 (Ethernet_Pair2_P); also elsewhere on the board
/EthC-: CM1#2.9 (Ethernet_Pair2_N); also elsewhere on the board
/EthD+: CM1#2.3 (Ethernet_Pair3_P); also elsewhere on the board
/EthD-: CM1#2.5 (Ethernet_Pair3_N); also elsewhere on the board
/UART_CTS1: CM1#2.29 (GPIO16); also elsewhere on the board
/UART_RTS1: CM1#2.50 (GPIO17); also elsewhere on the board
/UART_RXD1: CM1#2.51 (GPIO15); also elsewhere on the board
/UART_TXD1: CM1#2.55 (GPIO14); also elsewhere on the board
/~I2C_RESET: CM1#2.41 (GPIO25); also elsewhere on the board
GND: C1.2, C2.2, CM1#2.1 (GND), CM1#2.2 (GND), CM1#2.7 (GND), CM1#2.8 (GND), CM1#2.13 (GND), CM1#2.14 (GND), CM1#2.22 (GND), CM1#2.23 (GND), CM1#2.32 (GND), CM1#2.33 (GND), CM1#2.42 (GND), CM1#2.43 (GND), CM1#2.52 (GND), CM1#2.53 (GND), CM1#2.59 (GND), CM1#2.60 (GND), CM1#2.65 (GND), CM1#2.66 (GND), CM1#2.71 (GND), CM1#2.74 (GND), CM1#2.89 (WiFi_nDisable), CM1#2.91 (BT_nDisable), CM1#2.98 (GND), CM1#2.107 (GND), CM1#2.108 (GND), CM1#2.113 (GND), CM1#2.114 (GND), CM1#2.119 (GND), CM1#2.120 (GND), CM1#2.125 (GND), CM1#2.126 (GND), CM1#2.131 (GND), CM1#2.132 (GND), CM1#2.137 (GND), CM1#2.138 (GND), CM1#2.144 (GND), CM1#2.150 (GND), CM1#2.155 (GND), CM1#2.156 (GND), CM1#2.161 (GND), CM1#2.162 (GND), CM1#2.167 (GND), CM1#2.168 (GND), CM1#2.173 (GND), CM1#2.174 (GND), CM1#2.179 (GND), CM1#2.180 (GND), CM1#2.185 (GND), CM1#2.186 (GND), CM1#2.191 (GND), CM1#2.192 (GND), CM1#2.197 (GND), CM1#2.198 (GND), J10#2.1 (GND), J10#2.3 (GND), J10#2.9 (GND), J10#2.15 (GND), J10#2.21 (GND), J10#2.27 (GND), J10#2.33 (GND), J10#2.39 (GND), J10#2.45 (GND), J10#2.51 (GND), J10#2.57 (GND), J10#2.71 (GND), J10#2.73 (GND), J10#2.75 (GND), J10#2.S (SHIELD), U1.4 (A1), U1.6 (GND), U1.11 (GND); also elsewhere on the board
unnamed 152: J10#2.5 (PER3-); also elsewhere on the board
unnamed 153: J10#2.7 (PER+); also elsewhere on the board
unnamed 154: J10#2.11 (PET3-); also elsewhere on the board
unnamed 155: J10#2.13 (PET3+); also elsewhere on the board
unnamed 156: J10#2.17 (PER2-); also elsewhere on the board
unnamed 157: J10#2.19 (PER2+); also elsewhere on the board
unnamed 158: J10#2.23 (PET2-); also elsewhere on the board
unnamed 159: J10#2.25 (PET2+); also elsewhere on the board
unnamed 160: J10#2.29 (PER1-); also elsewhere on the board
unnamed 161: J10#2.31 (PER1+); also elsewhere on the board
unnamed 162: J10#2.35 (PET1-); also elsewhere on the board
unnamed 163: J10#2.37 (PET1+); also elsewhere on the board

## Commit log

2022-01-11 moved m.2 socket around
    [fruit.kicad_pcb]
2022-01-12 locked cm4 & mech footprints
    [fruit.kicad_pcb]
2022-01-12 fixed I2C ping indicator
    [cm4.kicad_sch, cm4hdmi.kicad_sch, cm4hirose.kicad_sch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]
2022-01-12 added inverter lib
    [cm4.kicad_sch]
2022-01-12 added ti buffer lib
    [cm4.kicad_sch, cm4hdmi.kicad_sch, cm4hirose.kicad_sch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]
2022-01-12 more indicator fixes
    [cm4.kicad_sch, fruit.kicad_sch]
2022-01-12 initial integration of i2c arbiter
    [cm4.kicad_sch, cm4hdmi.kicad_sch, cm4hirose.kicad_sch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]
2022-01-12 footprint assignment
    [cm4.kicad_sch, cm4hdmi.kicad_sch, cm4hirose.kicad_sch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]
2022-01-12 symbol bug fix
    [cm4.kicad_sch, fruit.kicad_pcb]
2022-01-12 board refresh
    [fruit.kicad_pcb]
2022-01-13 schematic cleanup
    [cm4.kicad_sch, cm4hdmi.kicad_sch, cm4hirose.kicad_sch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]
2022-01-14 work on control logic
    [cm4.kicad_sch, fruit.kicad_pcb, fruit.kicad_sch]
2022-01-15 schematic sheet renames
    [cm4.kicad_sch, fruit.kicad_sch, psu3v3.kicad_sch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]
2022-01-15 schematic bug fixes
    [cm4.kicad_sch]
2022-01-15 layout experiments
    [cm4m2mkey.kicad_sch, fruit.kicad_pcb]
2022-01-15 dp routing
    [fruit.kicad_pcb]
2022-01-16 merging changes for face plate conn
    [cm4.kicad_sch, cm4usb.kicad_sch, fruit.kicad_sch]
2022-01-16 connecterized faceplate, refreshed schematic
    [cm4.kicad_sch, cm4hdmi.kicad_sch, cm4hirose.kicad_sch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]
2022-01-16 placed hdmi conn
    [cm4.kicad_sch, cm4hdmi.kicad_sch, fruit.kicad_pcb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]
2022-01-16 hdmi dp routing
    [fruit.kicad_pcb]
2022-01-16 hdmi dp routed
    [fruit.kicad_pcb]
2022-01-16 microsd conn placed
    [fruit.kicad_pcb]
2022-01-17 hdmi dp cleanup
    [fruit.kicad_pcb]
2022-01-17 gnd vias
    [fruit.kicad_pcb]
2022-01-17 led changes
    [cm4usb.kicad_sch, fruit.kicad_pcb, fruit.kicad_sch]
2022-01-21 trued up facecm4 connector pinout
    [cm4.kicad_sch, psumon.kicad_sch]

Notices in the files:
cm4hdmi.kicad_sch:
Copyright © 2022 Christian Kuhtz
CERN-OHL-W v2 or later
